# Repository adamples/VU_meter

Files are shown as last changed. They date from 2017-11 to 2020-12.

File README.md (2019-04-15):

# OLED display VU meter — AVR/Arduino project

This project is to create digital version of a nice gadget that adds a little magic 
to any audio equipment: a [VU meter](https://en.wikipedia.org/wiki/VU_meter). Main design
goals are:
  - 2-channel operation,
  - as close to real VU-meter specification as possible,
  - high FPS, 60+ — no visible jumping of needle, as is common in other designs.

Project uses AVR ATMega88/168/328 (and ATMega48 if possible), so should be compatibile with
Arduino Uno boards. Small (and cheap) monochrome OLED modules with SSD1306 or SH1106 driver are 
employed as displays. Unlike other AVR VU meters that you can find on the web this one uses
quite complex analog circuitry (it can be much simpler if you are not as interested as me in
up-to-specs VU meter emulation).

Here's a video showing test of VU meter prototype:

Background and needle animation test video (https://www.youtube.com/watch?v=tU8fmWirxTw)

## Building The Project

To build hex file you'll need:
  - avr-gcc,
  - GNU make,
  - Python 2.7 or 3.
For windows you can use this distribution of gcc and make: http://blog.zakkemble.co.uk/avr-gcc-builds/

Before compilation please modify [src/config.h](src/config.h) file to set proper OLED controller type and [Makefile](Makefile) to set uC type and oscillator frequency (F_CPU).

To create hex file type:
```
$ make all
```
This will create `build/main.hex` that you can use to flash your device.

__Note: This is Work In Progress design. To make it work for you you'll most probably need to modify it in one way or another.__

## Hardware Design

If you would like to make VU meter yourself here are some useful files for you:
  - [hardware/vu_meter.sch](hardware/vu_meter.sch) — schematic (in Eagle 8 format)
  - [hardware/vu_meter.brd](hardware/vu_meter.brd) — PCB design (in Eagle 8 format)
  - [hardware/vu_meter_sch.pdf](hardware/vu_meter_sch.pdf) — schematic as PDF
  - [hardware/bom.ods](hardware/bom.ods) — bill of materials (open document)
  - [hardware/vu_meter.zip](hardware/vu_meter.zip) — gerber files ready for production

PCB is designed as a module to be included in other devices so all signals are connected using goldpin headers:
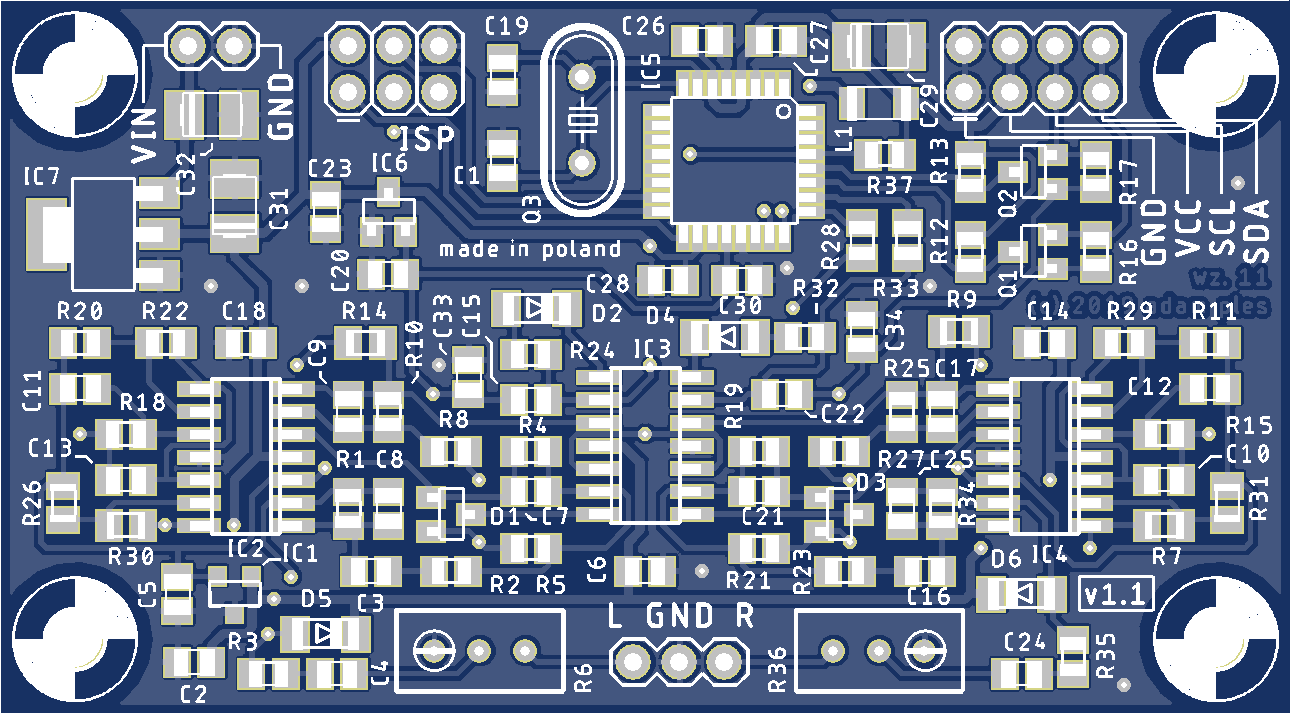
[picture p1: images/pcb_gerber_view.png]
VU meter PCB design preview

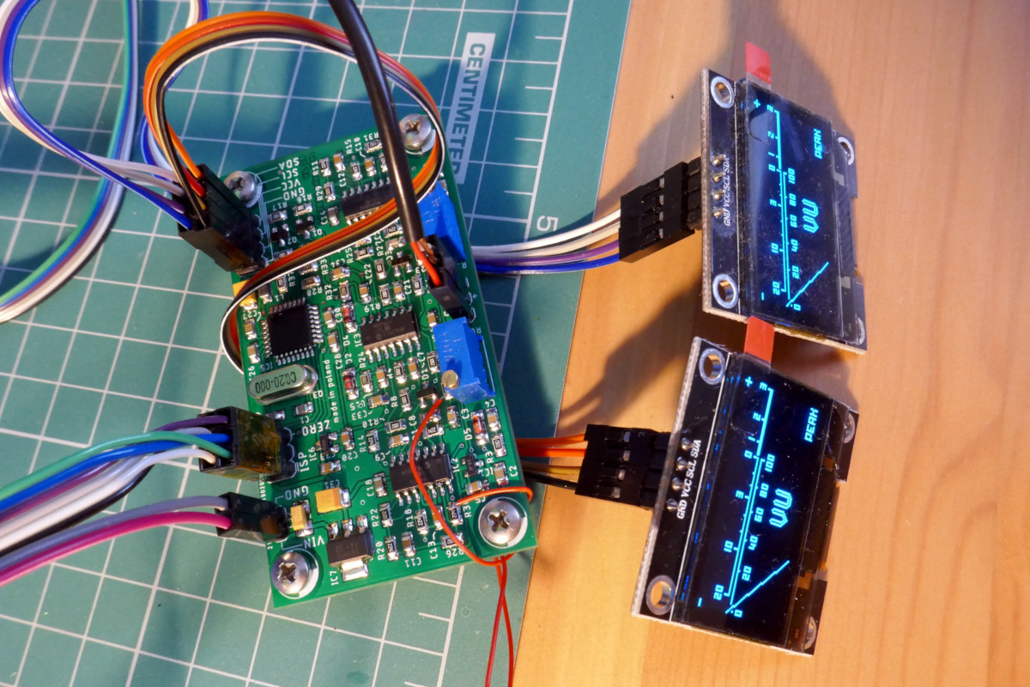
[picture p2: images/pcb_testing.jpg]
Assembled VU meter PCB picture


There is also Arduino UNO shield (rev.3) design, altough it's not very polished version:
  - [hardware/arduino_shield.sch](hardware/arduino_shield.sch) — schematic (in Eagle 8 format)
  - [hardware/arduino_shield.brd](hardware/arduino_shield.brd) — PCB design (in Eagle 8 format)

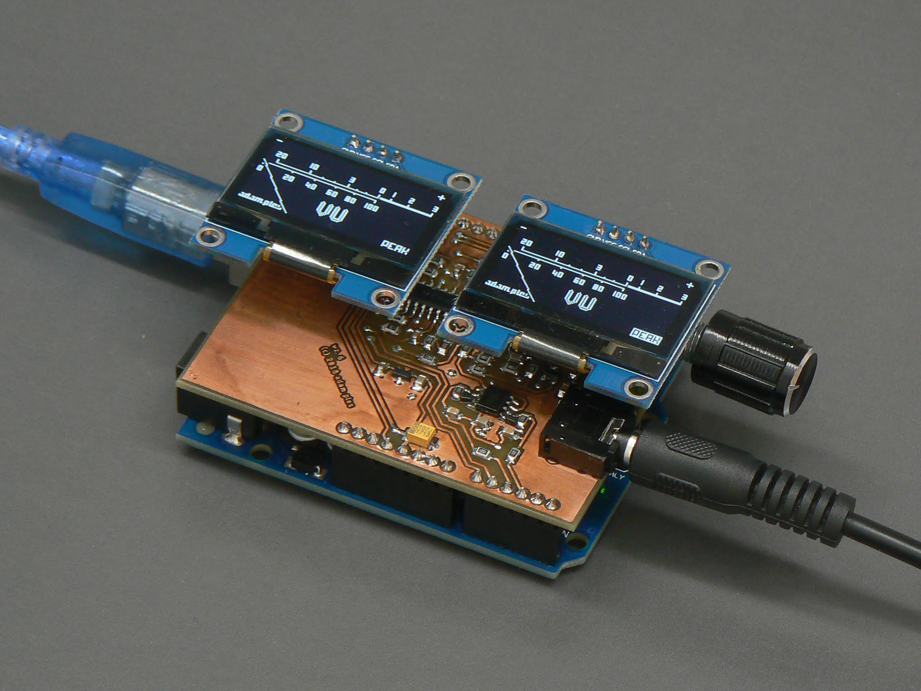
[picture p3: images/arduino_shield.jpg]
Assembled Arduino Shield PCB picture


Full documentation will be included in the future, as the project progresses.

For now here's very high-level block diagram of the device:

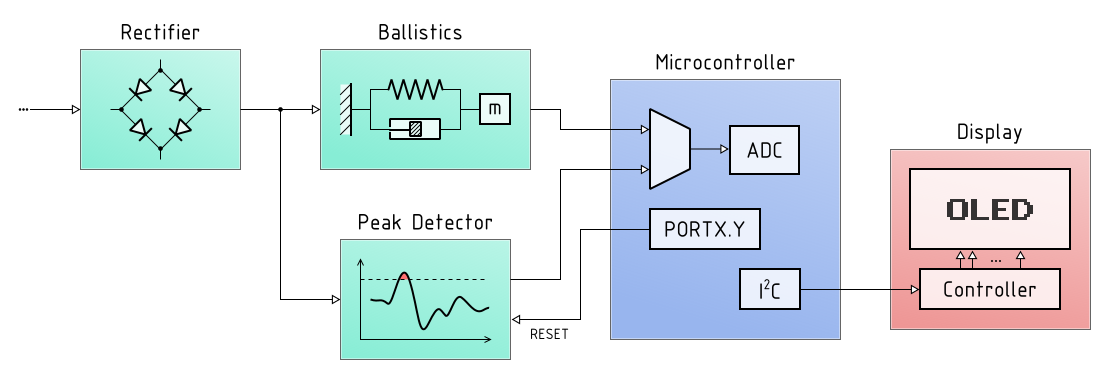
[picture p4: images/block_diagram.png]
Block diagram of AVR/OLED VU meter


Second analog channel and OLED display were omitted for the sake of brevity.

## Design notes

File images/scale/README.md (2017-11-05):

# Defining VU meter scale

To convert from _VU_ scale to _dBu_ we just add 4, so 0VU becomes +4dBu. _dBu_ scale can converted to V<sub>RMS</sub> using equation:
U_Vrms = sqrt(0.6) * 10^(U_dBu/20)

If we assume that VU meter scale will range from 0V<sub>rms</sub> to 1.734V<sub>rms</sub> (+3VU) and the needle can from vertical position by +-42° we get following angles for VU values:

| U [VU] | U [dBu] | U [V<sub>rms</sub>] | angle [°] |
|--:|--:|--:|--:|
|-20|-16|0.123V|-35°|
|-19|-15|0.138|-34|
|-18|-14|0.155|-33|
|-17|-13|0.173|-32|
|-16|-12|0.195|-32|
|-15|-11|0.218|-30|
|-14|-10|0.245|-29|
|-13| -9|0.275|-28|
|-12| -8|0.308|-26|
|-11| -7|0.346|-24|
|-10| -6|0.388|-22|
| -9| -5|0.436|-20|
| -8| -4|0.489|-18|
| -7| -3|0.548|-15|
| -6| -2|0.615|-12|
| -5| -1|0.690| -8|
| -4| +0|0.775| -4|
| -3| +1|0.869|  0|
| -2| +2|0.975|  5|
| -1| +3|1.094| 11|
| +0| +4|1.228| 17|
| +1| +5|1.377| 24|
| +2| +6|1.546| 32|
| +3| +7|1.734| 41|

For percentage scale we get the following:

| U [% 0dBu] | U [V<sub>rms</sub>] | angle [°] |
|--:|--:|--:|
|0|0.000|-41|
|5|0.061|-38|
|10|0.123|-35|
|15|0.184|-32|
|20|0.246|-29|
|25|0.307|-26|
|30|0.368|-23|
|35|0.430|-20|
|40|0.491|-18|
|45|0.552|-15|
|50|0.614|-12|
|55|0.675| -9|
|60|0.737| -6|
|65|0.798| -3|
|70|0.859|  0|
|75|0.921|  3|
|80|0.982|  5|
|85|1.044|  8|
|90|1.105| 11|
|95|1.166| 14|
|100|1.228| 17|

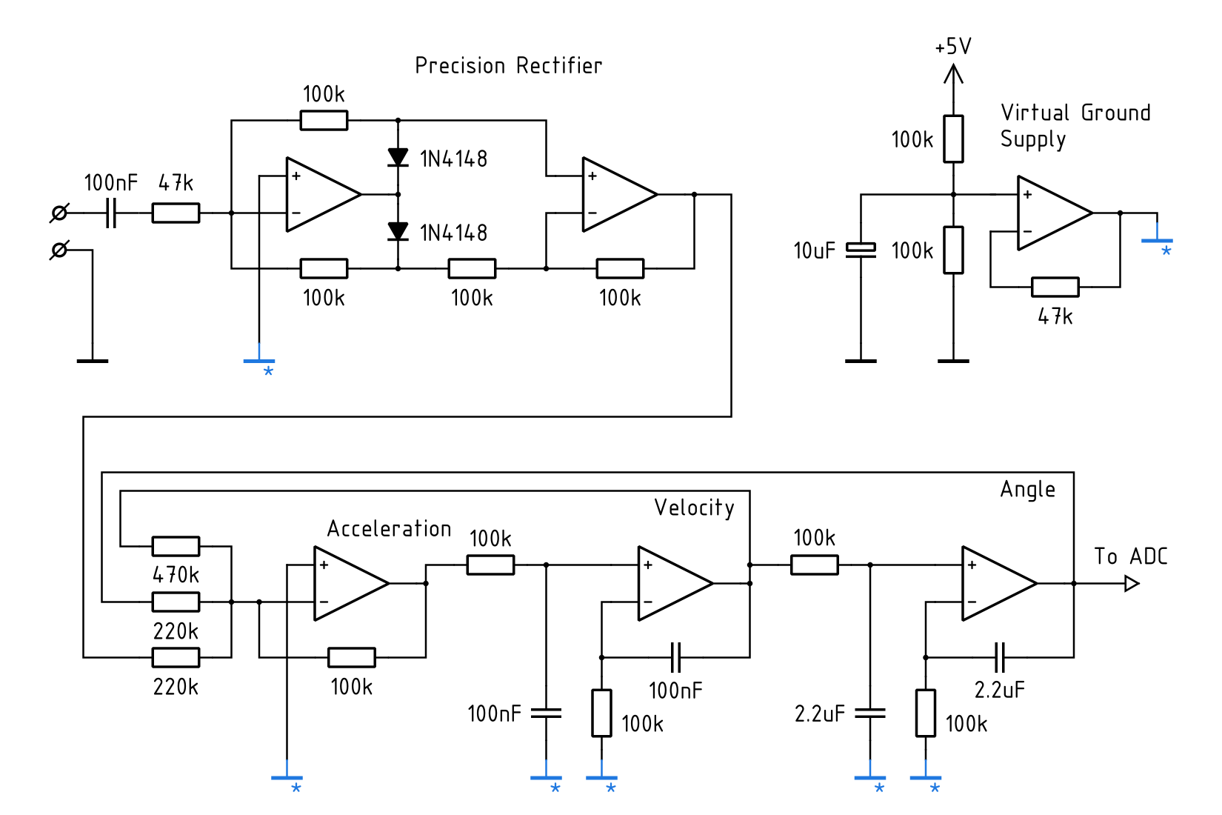
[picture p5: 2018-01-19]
images/analog_simulation.png

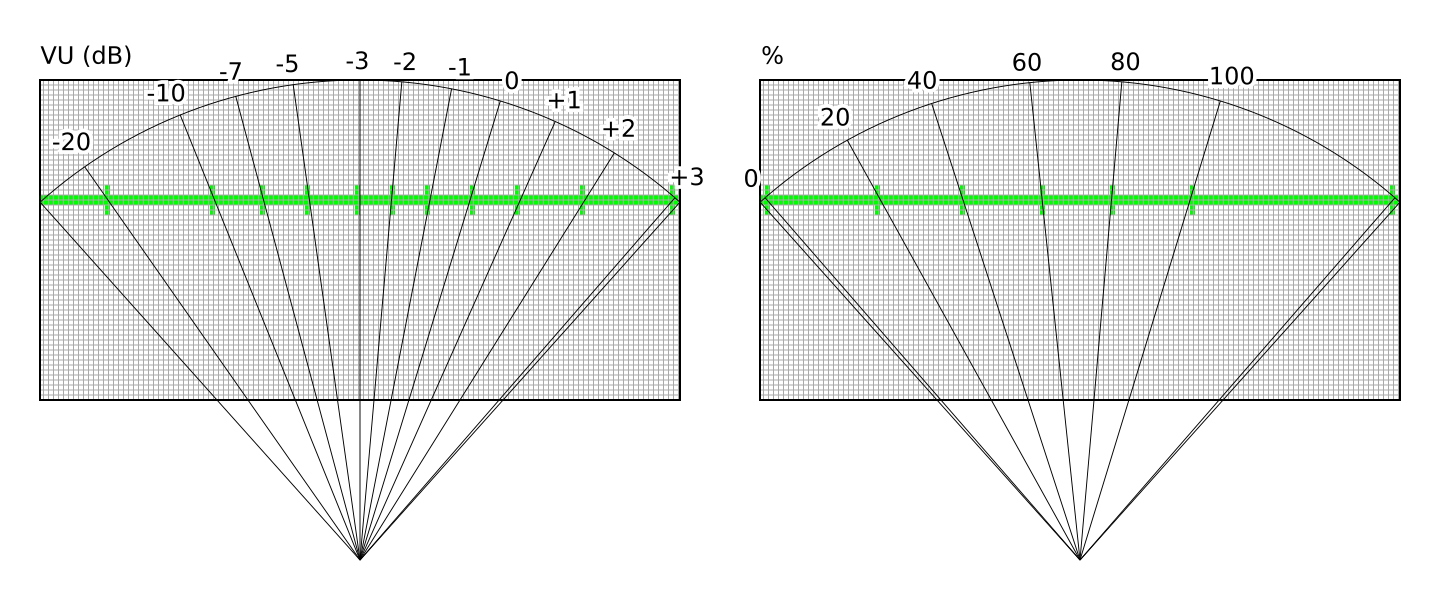
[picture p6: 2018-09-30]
images/scale/scale.png

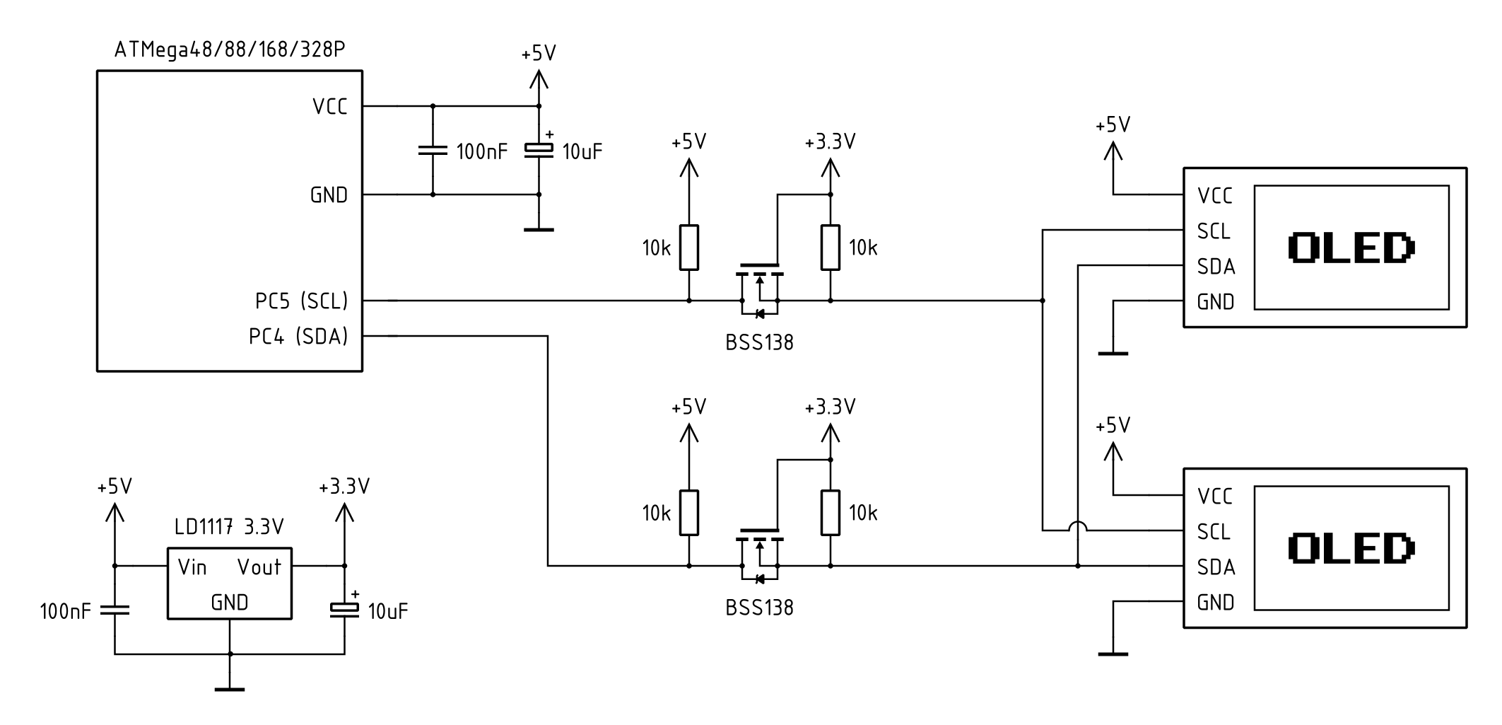
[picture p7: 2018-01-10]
images/oled_connection.png

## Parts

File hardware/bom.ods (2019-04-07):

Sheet: Short
Part Name | Technology | Package | Value | Add. Params | Quantity
Resistors | thin film | 0805 | 10k | 1% | 15
 | thick film | 0805 | 220R |  | 2
 |  |  | 1k |  | 2
 |  |  | 22k |  | 2
 |  |  | 47k |  | 2
 |  |  | 82k |  | 2
 |  |  | 220k |  | 10
 | trimmer | 3296W | 10k |  | 2
Capacitors | ceramic | 0805 | 22pF |  | 2
 |  |  | 33pF |  | 2
 |  |  | 220pF |  | 4
 |  |  | 47nF |  | 2
 |  |  | 100nF |  | 10
 |  |  | 220nF |  | 2
 |  |  | 330nF |  | 4
 |  |  | 470nF |  | 2
 |  |  | 1uF |  | 2
 |  |  | 10uF |  | 1
 | tantalum | 1210 | 10uF | 16V | 1
 |  |  | 100uF | 6.3V | 2
Diodes |  | SOD80 | 1N4148 |  | 2
 |  |  | BAT85 |  | 2
 |  | SOT23 | BAS70-04 |  | 2
Transistors |  | SOT23 | BSS138 |  | 2
Integrated Circuits | linear regulator | SOT223 | 1117-5.0 |  | 1
 |  | SOT23 | MCP1700*33 |  | 1
 |  | SOT23 | MCP1525 |  | 1
 | op amp | SO14 | MCP604 |  | 1
 |  |  | MCP6004 |  | 2
 | microcontroller | TQFP32 | ATmega88P |  | 1
Others | crystal resonator | HC49/S | 20MHz |  | 1
 | choke | 1210 | 10uH |  | 1
 | pin headers |  | 1x2 |  | 1
 |  |  | 1x3 |  | 1
 |  |  | 2x3 |  | 1
 |  |  | 2x4 |  | 1

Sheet: Full
Part Name | Technology | Package | Value | Part Name | Add. Params
Resistors | thin film | 0805 | 10k | R2 | 1%
 |  |  |  | R4 | 1%
 |  |  |  | R5 | 1%
 |  |  |  | R8 | 1%
 |  |  |  | R10 | 1%
 |  |  |  | R19 | 1%
 |  |  |  | R21 | 1%
 |  |  |  | R23 | 1%
 |  |  |  | R25 | 1%
 |  |  |  | R27 | 1%
 | thick film | 0805 | 220R | R24
 |  |  |  | R32
 |  |  | 1k | R28
 |  |  |  | R33
 |  |  | 10k | R12
 |  |  |  | R13
 |  |  |  | R16
 |  |  |  | R17
 |  |  |  | R37
 |  |  | 22k | R3
 |  |  |  | R35
 |  |  | 47k | R26
 |  |  |  | R31
 |  |  | 82k | R22
 |  |  |  | R29
 |  |  | 220k | R1
 |  |  |  | R7
 |  |  |  | R9
 |  |  |  | R11
 |  |  |  | R14
 |  |  |  | R15
 |  |  |  | R18
 |  |  |  | R20
 |  |  |  | R30
 |  |  |  | R34
 | trimmer | 3296W | 10k | R6
 |  |  |  | R36
Capacitors | ceramic | 0805 | 22pF | C1
 |  |  |  | C19
 |  |  | 33pF | C8
 |  |  |  | C25
 |  |  | 220pF | C7
 |  |  |  | C9
 |  |  |  | C17
 |  |  |  | C21
 |  |  | 47nF | C15
 |  |  |  | C22
 |  |  | 100nF | C2
 |  |  |  | C6
 |  |  |  | C14
 |  |  |  | C18
 |  |  |  | C26
 |  |  |  | C27
 |  |  |  | C28
 |  |  |  | C30
 |  |  |  | C33
 |  |  |  | C34
 |  |  | 220nF | C4
 |  |  |  | C24
 |  |  | 330nF | C10
 |  |  |  | C11
 |  |  |  | C12
 |  |  |  | C13
 |  |  | 470nF | C3
 |  |  |  | C16
 |  |  | 1uF | C5
 |  |  |  | C23
 |  | 0805 | 10uF | C20
 | tantalum | 1210 | 10uF | C32 | 16V
 |  |  | 100uF | C29 | 6.3V
 |  |  |  | C31 | 6.3V
Diodes |  | SOD80 | 1N4148 | D2
 |  |  |  | D4
 |  |  | BAT85 | D5
 |  |  |  | D6
 |  | SOT23 | BAS70-04 | D1
 |  |  |  | D3
Transistors |  |  | BSS138 | Q1
 |  |  |  | Q2
Integrated Circuits | linear regulator | SOT223 | 1117-5.0 | IC7
 |  | SOT23 | MCP1700*33 | IC6
 |  | SOT23 | MCP1525 | IC1
 | op amp | SO14 | MCP604 | IC3
 |  |  | MCP6004 | IC2
 |  |  |  | IC4
 | microcontroller | TQFP32 | ATmega88P | IC5
Others | crystal resonator | HC49/S | 20MHz | Q3
 | choke | 1210 | 10uH | L1

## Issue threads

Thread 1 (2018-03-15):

Screen refresh rate

capezoloh, 2018-03-15:
Neat little project you got here. Most of these kind of projects I see on youtube have really poor screen update rate. Is this true for yours aswell?

adamples, 2018-03-16:
Yeah, I also noticed it. There are several reasons for this. Most projects use u8g2, which is a great general-purpose library, but with some limitations arising from it's design goals. In the picture loop mode it refreshes the whole screen, which takes considerable amount of time just to transfer the data (~24ms for I2C at 400kHz). Additionally it uses synchronous I2C driver, so it can't render while sending the data either. This yields FPS in range of 20+.

In this project I aimed at different approach: asynchronous I2C, using HW available in atmega, and partial screen updates. It also uses sprites instead of drawing primitives directly to buffer. It all requires additional data and flash memory, but in the end you get update time of ~7ms, so more than 60FPS for 2 displays (it's more than display's actual frame rate I believe). It gives an impression of really smooth movement.

The code was tailored for purpose of displaying the needle against fixed background. It can be changed to do picture-loop style drawing or to use framebuffer, and calculating an update can be generalized too, but it's not the purpose of this project.

RaffRJ, 2018-05-05:
Hi Adam.
Its me raffy turc on youtube.
I have downloaded and installed python 3.6 and compiled the 2 py files. Im getting error. What could be possibly the problem?

adamples, 2018-05-05:
@RaffRJ Can you please open new issue for this? Also, you have to provide at least some error message, describe what commands you executed. Otherwise it's really hard to tell.

Closed 2018-05-05.

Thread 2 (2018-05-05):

Compiling problems in windows

RaffRJ, 2018-05-05:
Using windows 64-bit machine

What I have done:
Copy the make.exe inside a folder with the SRC folder in it. When I envoke make, 1st problem  it was looking for missing file.
[IMG]http://i65.tinypic.com/3145mhh.jpg[/IMG]

Now I have downloaded and installed python 3.6

Run the app and loaded python files. It returns error.
[IMG]http://i63.tinypic.com/34t1gup.jpg[/IMG]

adamples, 2018-05-06:
Ok, now I see the problem.

First of all you shouldn't copy `make` into repository. You just need to add it's directory to the PATH environment variable. Then you'll be able to run it from any directory. _Please remove it before proceeding with these instructions_.

Let's say you downloaded avr-gcc from here: http://blog.zakkemble.co.uk/avr-gcc-builds/ and unpacked to `C:\avr-gcc-7.3.0-x64-mingw\`. Then you open cmd, and add it to your PATH:

```
C:\vum> set PATH=C:\avr-gcc-7.3.0-x64-mingw\bin\;%PATH%
```

_Please double check if this is a valid path to bin directory, which contains `avr-gcc.exe` and `make.exe`_.

Now you can check if avr-gcc is recognized as a command:

```
C:\vum> avr-gcc --version
avr-gcc (GCC) 7.3.0
Copyright (C) 2017 Free Software Foundation, Inc.
This is free software; see the source for copying conditions.  There is NO
warranty; not even for MERCHANTABILITY or FITNESS FOR A PARTICULAR PURPOSE.
```

Same with make:

```
C:\vum> make --version
GNU Make 4.2.1
Built for Windows32
Copyright (C) 1988-2016 Free Software Foundation, Inc.
License GPLv3+: GNU GPL version 3 or later <http://gnu.org/licenses/gpl.html>
This is free software: you are free to change and redistribute it.
There is NO WARRANTY, to the extent permitted by law.
```

And Python:

```
C:\vum> python --version
Python 3.6.5
```

If all of that works, just execute `make` and you should get your `build\main.hex` file.

If you want to add avr-gcc to PATH permamently, use `setx` command:

```
C:\vum> setx PATH=C:\avr-gcc-7.3.0-x64-mingw\bin\;%PATH%
```

RaffRJ, 2018-05-07:
Update:

Hardware now working. Xtal changed to 20MHz. I have tried your older code and meter needle never moves. Tried all analog inputs.

And then I compiled again your latest code "using single lcd" . Now the meter shows pegged. Still no response from analog input pin/s (assuming this gets audio signal from A0)
[IMG]http://i68.tinypic.com/se7qq1.jpg[/IMG]

RaffRJ, 2018-05-07:
Got it!

So this is using Aref.no wonder 😀. My bad. Anyways at what voltage does the final op-amp output is with 0v input signal? Around 2.5v? Assuming using rail2rail output? I have here mcp602. Havent wired it yet according to your diagram.

adamples, 2018-05-07:
Yes, it will be somewhere around virtual ground, so 2.5V. If I remember correctly with input of sine wave with amplitude of ~0.5V it goes down to around 1.3V (I may be wrong about that, I tried many versions of this circuit).

In this code (main.c:93):
```
int16_t angle_l = (int32_t) (498 - adc_l) * 128 / 164;
```

498 is "zero" level, and 164 is scaling factor. You can adjust it to be more or less sensitive. Additionally you can change gain of input stage by changing the 47k resistor.

In my prototype I used mcp6002 which has both rail-to-rail inputs and outputs.

RaffRJ, 2018-05-07:
Copy that. So if I change 498 to 0, would this mean also as "referenced to GND"?

and how do I turn off or disable Aref?

RaffRJ, 2018-05-09:
Adam

I have tried value of 800. The needle is in the "peg" position. And when I touch op-amp input, meter deflects to left. Quiet the opposite from your video. What couls be problem here? Its like the adc is configured for "reverse"

RaffRJ, 2018-05-09:
Adam.

Dis-regard my earlier post. Its working ok now. Ive scoped out the output of op-amp circuit. It registers virtual ground+sensed audio(positive voltage). It was the code that was inverting the results. Done some bit of google search(my mind kinda rusty with coding 😂) . Will rotate again 180° the bitmap image to "standard" orientation. Though I may add a bit of hardware mod at the adc input. Adjustable midpoint voltage then ac couple it to the op-amp/s front-end so I wouldnt be bothered adjusting code for "zero-ing""the meter needle.

Better if I could assign an un-used adc input to pot and map it (adding integer value) to the AN0 reading..but thats out of my head now.
Will update a video later...

Could you suggest me an easier way of "zero-ing"  the needle on your code?
Was thinking 8-bits(?) so 1024(or 1023) divide that in half since op-amp is referenced to 1/2 vcc.
Then add maybe in increments of 5 ..you get my point.. lol.

I need some sleep 1st. Laters man!  And thanks for this vu project of yours.
Nice addition to my desktop eycandy oled display/s.

adamples, 2018-05-14:
Ok, I added quick fix to both main and single_display branches: https://github.com/adamples/VU_meter/commit/e31dd53ddfc5ed11ee5e7e64ef18e89d4039c249

Currently the code checks for needle angle to make peak indicator visible (main.c:106):

```
PEAK_INDICATOR_SPRITE.sprite.visible = (angle_l > 192);
```

Closed 2018-05-23.

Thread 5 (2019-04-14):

The Circuit Diagram

classic-audio, 2019-04-14:
I am back and I am still thinking of building this great project.
To start - I would like to start with the circuit diagram /PCB.
I tried to open your eagle files in eagle 9.2.2  - but I am getting the message: This is not an eagle file.
I can open eagle files from eagle 6.x in eagle 9.2.2 so I expect also that eagle 8.x files should be possible to open but no.
Do you know a reason ?
Or would you be so kind to send the circuit in a PDF file?
Best regards
Frede Kristensen

adamples, 2019-04-15:
Did you try these files? (I put the wrong names in readme by mistake)
https://github.com/adamples/VU_meter/blob/master/hardware/vu_meter_2.sch
https://github.com/adamples/VU_meter/blob/master/hardware/vu_meter_2.brd

I will fix that and add schematic in pdf later today.

adamples, 2019-04-15:
I uploaded the circuit diagram here:
https://github.com/adamples/VU_meter/blob/master/hardware/vu_meter_sch.pdf

classic-audio, 2019-04-15:
Thank you very much. Really interresting for me to study you solution.
(The analog circuit).
I will have a look to night.

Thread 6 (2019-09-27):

Programming

shtv-electro, 2019-09-27:
Hello. Tell me how to program a project (I am using Atmega328P (Arduino nano), 16MHz, OLED1306). I am not familiar with Python language, and would like more detailed instruction. Thanks

adamples, 2019-10-09:
Hi, if you know how to flash your arduino with hex file you can use the ones from this zip: https://github.com/adamples/VU_meter/releases. It doesn't require Python.

shtv-electro, 2019-10-22:
Hey. I flashed a hexadecimal file, the screen is black. Tried to flash the standard code of the display and it works. Maybe your code is not the address of the display? I want you ask do code under displays 1306 with addresses: 0x3C; 0x3C. Atmega328p, 16 MHz.

adamples, 2019-10-25:
Hi, it won't work since display addresses need to be different. If you're able to change address of one of them (probably by resoldering some resistor on board) then I can compile hex file for you.

Juroo5, 2020-10-15:
Hello, I'm joining DamianRaistrick's previous question. I'm trying to run a program on an Arduino Nano (Atmega328P). I have displays with the SD1309 controller (exactly these https://www.aliexpress.com/item/33024448944.html?spm=a2g0s.9042311.0.0.27c64c4dNouTa4)
The displays are connected in I2C mode to arduino (PC5 -> SCL, PC4 -> SDA) . On one, the address is changed by changing the CS level. With the I2C scanner the addresses are 0x3C and 0x3D.
In the makefile I changed :
BOARD? = WZ10 to BOARD? = ARDUINO_UNO
In config file I changed :
#define OLED_DRIVER (OLED_DRIVER_SD1309)
...
#define DISPLAY_A_ADDRESS (0x3C)
#define DISPLAY_B_ADDRESS (0x3D)
...
After uploading the program (with generated HEX and AVRDUDESS), nothing will appear on the displays.
It's possible that arduino I2C scanner (scanner in arduino example sketchs) see different address than this program ?
Or is there something I missed ? Can you help me? Thank you.

adamples, 2020-10-15:
Hi! One common problem is that those displays even when using the same driver designation are not always exactly the same. I think this one may need reset signal during initialization. Have you tried displaying something using other libraries/arduino sketches? If so, which library and how did you connect the reset line?

Juroo5, 2020-10-15:
Hi! Thank you for the quick reply. For the reset pin I connected a 22uf capacitor between RES and GND and a 10k resistor between VCC and RES. Yes, I tested these displays on the example of Adafruit SSD1306 library : https://photos.app.goo.gl/9cgTZD8fZcefB1yZA
It's of course OLED_DRIVER_SSD1309, I'm sorry for the bad typing.
In the end, it works! Well thank you ! The problem was the addresses, I correct them to 0x78 and 0x7a and it works.

cghercoias, 2020-12-20:
Hi Adam,

I just found your project and I must say it is impressive. I have just one SH1106 display and I wanted to try your code. I did compile successfully the code on my Mac, changing in the makefile. But the display does not lit.
It is wired just GND, VCC, SDA and SCL. I did test the display with the Adafruit example code for this display and works fine. When I upload the main.hex does not lit anymore.  The address on the back of the display (where the resistor is soldered) is 0x78. However, in the Adafruit example is 0x3C and works. In the config.h is 0x78 and 0x7A. I did try and compile the main.hex with 0x3C for DISPLAY_A_ADDRESS and 0x3D for DISPLAY_B_ADDRESS and still didn't show anything on the display.
I don't know where to look anymore.
..
BOARD? = WZ10 to BOARD? = ARDUINO_UNO
..
Here is how I am burning the main.hex file on the ArduinoNANO

catalin@DadMacPro VU_meter-master % /Users/catalin/Library/Arduino15/packages/arduino/tools/avrdude/6.3.0-arduino17/bin/avrdude -C/Users/catalin/Library/Arduino15/packages/arduino/tools/avrdude/6.3.0-arduino17/etc/avrdude.conf -v -patmega328p -carduino -P/dev/cu.usbserial-1410 -b115200 -D -Uflash:w:build/RELEASE/main.hex:i

avrdude: Version 6.3-20190619
         Copyright (c) 2000-2005 Brian Dean, http://www.bdmicro.com/
         Copyright (c) 2007-2014 Joerg Wunsch

         System wide configuration file is "/Users/catalin/Library/Arduino15/packages/arduino/tools/avrdude/6.3.0-arduino17/etc/avrdude.conf"
         User configuration file is "/Users/catalin/.avrduderc"
         User configuration file does not exist or is not a regular file, skipping

         Using Port                    : /dev/cu.usbserial-1410
         Using Programmer              : arduino
         Overriding Baud Rate          : 115200
         AVR Part                      : ATmega328P
         Chip Erase delay              : 9000 us
         PAGEL                         : PD7
         BS2                           : PC2
         RESET disposition             : dedicated
         RETRY pulse                   : SCK
         serial program mode           : yes
         parallel program mode         : yes
         Timeout                       : 200
         StabDelay                     : 100
         CmdexeDelay                   : 25
         SyncLoops                     : 32
         ByteDelay                     : 0
         PollIndex                     : 3
         PollValue                     : 0x53
         Memory Detail                 :

                                  Block Poll               Page                       Polled
           Memory Type Mode Delay Size  Indx Paged  Size   Size #Pages MinW  MaxW   ReadBack
           ----------- ---- ----- ----- ---- ------ ------ ---- ------ ----- ----- ---------
           eeprom        65    20     4    0 no       1024    4      0  3600  3600 0xff 0xff
           flash         65     6   128    0 yes     32768  128    256  4500  4500 0xff 0xff
           lfuse          0     0     0    0 no          1    0      0  4500  4500 0x00 0x00
           hfuse          0     0     0    0 no          1    0      0  4500  4500 0x00 0x00
           efuse          0     0     0    0 no          1    0      0  4500  4500 0x00 0x00
           lock           0     0     0    0 no          1    0      0  4500  4500 0x00 0x00
           calibration    0     0     0    0 no          1    0      0     0     0 0x00 0x00
           signature      0     0     0    0 no          3    0      0     0     0 0x00 0x00

         Programmer Type : Arduino
         Description     : Arduino
         Hardware Version: 3
         Firmware Version: 4.4
         Vtarget         : 0.3 V
         Varef           : 0.3 V
         Oscillator      : 28.800 kHz
         SCK period      : 3.3 us

avrdude: AVR device initialized and ready to accept instructions

Reading | ################################################## | 100% 0.00s

avrdude: Device signature = 0x1e950f (probably m328p)
avrdude: safemode: lfuse reads as 0
avrdude: safemode: hfuse reads as 0
avrdude: safemode: efuse reads as 0
avrdude: reading input file "build/RELEASE/main.hex"
avrdude: writing flash (5762 bytes):

Writing | ################################################## | 100% 1.03s

avrdude: 5762 bytes of flash written
avrdude: verifying flash memory against build/RELEASE/main.hex:
avrdude: load data flash data from input file build/RELEASE/main.hex:
avrdude: input file build/RELEASE/main.hex contains 5762 bytes
avrdude: reading on-chip flash data:

Reading | ################################################## | 100% 0.77s

avrdude: verifying ...
avrdude: 5762 bytes of flash verified

avrdude: safemode: lfuse reads as 0
avrdude: safemode: hfuse reads as 0
avrdude: safemode: efuse reads as 0
avrdude: safemode: Fuses OK (E:00, H:00, L:00)

avrdude done.  Thank you.
...

adamples, 2020-12-21:
So the addresses in config should be 0x78/0x7a. 0x3c and 0x3d is the same address written in different convention (it's just right-shifted by 1 bit). Did you try to connect two displays or just one? It's not clear from your question. This project requires two with different addresses, otherwise it won't display anything.

cghercoias, 2020-12-21:
0x3C | 0 0 1 1   1 1 0 0
0x3D | 0 0 1 1   1 1 0 1

0x78 | 0 1 1 1   1 0 0 0
0x7A | 0 1 1 1   1 0 1 0

I see that now, it is right-shifted. How come I didnt see that before. :-)
I connected only one display, SH1106. I will try with two SSD1306 as I dont have two SH1106s.
Thank you so much

cghercoias, 2020-12-22:
I made it work with 2 SSD1306s. Had to modify the address of one of them by cutting a pad and solder it to VCC.
Pictures attached.
According to SSD1306 PDF document ( [SSD1306.pdf](https://github.com/adamples/VU_meter/files/5732094/SSD1306.pdf) - page 20 ) :

_"The slave address is following the start condition for recognition use. For the SSD1306, the slave
address is either “b0111100” or “b0111101” by changing the SA0 to LOW or HIGH (D/C pin acts as
SA0)."_
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

So, I did a little surgery on one display, D/C pin aka SA0 is pin 15:
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

Final result:
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

THANK YOU SO MUCH ADAM !!!

Merry Christmas and a Happy New Year! Stay safe!

adamples, 2020-12-23:
Very glad to hear it worked for you, Marry Christmas to you too!

cghercoias, 2020-12-23:
Now I have another issue. The needles don't move. I've applied a signal from my laptop headphone jack on both A0 and A1 (inserted 1uF electrolytic capacitor on each channel to decouple any DC component, if present) and the only thing that sometimes happens is PEAK blinks. Looking at your electronics diagram, I noticed you've connected ARef to 3.3V. So I placed a jumper between 3.3V and ARef (behind those resistors) and the needles jumped to max and stayed there. I'm able to watch with the osciloscope the audio signal getting to A0 and A1, I can vary the amplitude from 0 to 1.5V. I did not connect anything to the A2 and A3 for PEAK. What am I missing?

adamples, 2020-12-25:
Well, if you're using different analog circuitry at the inpuit it will require some hacking on your part. The program is expecting AREF to be 3.3V and voltage when there is no signal at the input should be 2.5V (there is 2.5V reference source on the schematic, MCP1525 IIRC). When needle is at 0VU the voltage at the input should go _down_ to about 1.1V. You can find the code in calibration.h/c.

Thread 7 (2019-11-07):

Display Question

DamianRaistrick, 2019-11-07:
Hi Adam
Really excellent project!
I'm attempting to get this to work on a couple of SH1106 displays with addresses 0x3c and 0x3d. I've managed to edit the config.h file to reflect the addresses and make the main.hex file (using terminal on my mac). I have managed to upload to an Arduino Uno using HexUploader but nothing appears on the displays.
I've tested the displays using the adafruit and U8Glib example code and they work fine on on I2C.
Is there anything else I should be adjusting before making the hex file for these displays?
Many thanks
Damian

adamples, 2019-11-08:
Hi! Yes, in fact you need to edit BOARD variable in Makefile: replace "BOARD?=WZ10" in 2nd line with "BOARD?=ARDUINO_UNO".

This project may not be of the same quality as u8glib, so if it still doesn't work, let me know ;)

DamianRaistrick, 2019-11-08:
Thanks so much Adam
Your project is inspiring! I only mentioned the other libraries/examples because I wanted to show I'd tested my displays were generally working ok with I2C.
I knew there was something I was doing wrong! :)
I'll try editing the Board variable as you suggest and let you know how I get on.
Thanks again
Damian

DamianRaistrick, 2019-11-08:
Hello again!
I edited the make file as instructed, but sadly I still have a blank display.
I wonder if trying a windows environment (rather than my mac) would make any difference?!
Incidentally the displays I'm using are these:
https://hobbycomponents.com/displays/621-3-sh1106-uoled-display-module-white
with the jumper set for I2C. DC pin sets the address to either 0x3C or 0x3D. CS tied to ground and RES is the reset pin normally tied to High.
Any other ideas?
Thanks
Damian

DamianRaistrick, 2019-11-08:
I've just tried an experiment to check HexUploader was flashing the Uno properly. I exported a hex file from the Arduino IDE of the Adafruit example code and flashed that using HexUploader and it worked fine.
So it looks like there's still something I'm doing wrong with the compiling of the hex file for your code.

DamianRaistrick, 2019-11-11:
Hi again Adam
OK, so now I have bought some different I2C displays (1306) and I've tried the code you have already complied to hex with my Uno (using your mega328p_16Mhz.hex) and things still don't work for me - blank displays again.
Going back to compiling myself - with my new 1306 I2C displays on 07xA and 07xB - what exactly should I be doing with the config.h file in terms of editing it and running it on my Arduino Uno?
In your readme you say to edit the config.h file to "set proper OLED controller type". My guess is I'm not doing that properly.
I see the list of controller type definitions in the config.h file, but the remark says not to edit these constants. So how should I edit the config.h file to set the controller type to 1306?
Many thanks
Damian

DamianRaistrick, 2019-11-11:
Don't worry! I now realise that these new displays do not have the addresses 0x7A and 0x78 when used with Arduino - they are 0x3C and 0x3D because of the way Arduino truncates the addresses.
The more I use Arduino, the more limited I realise it is!
I've returned the new displays and will now give up! I've wasted so much time trying to get this to work for me.
Nice project though! :-)
Feel free to close this 'issue'.
Best
Damian

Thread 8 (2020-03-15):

PCB Production

ezhik1, 2020-03-15:
Hej @adamples ! Absolute stellar project! I too, find the ballistics and smoothing in analog vu meter very important :) My VU meters, one of my first [here](https://www.youtube.com/watch?v=RjcTkzzANwM), have all been based on lm3916 ICs and with a much larger footprint, so it would be real fun to play with this compact scale!

I saw most of your prototypes on youtube and looks like you've got the board produced already, did you have it made locally, or do you have something already set up with a factory in China?

The BOM you have listed doesn't have designators, but I used Eagle to generate one from the .sch file, and it looks to be complete.

If I get the board produced, I want to make sure I've got the BOM right, Could you have a look?  Also, what was overall parts cost? I'm trying to see how economical this little visualizer will turn out.

Dziekuje!

male pin   header: 1*2pin 2.54mm | 1 |   | CONN_02 | 1X02 | J2 | Multi connection point. Often   used as Generic Header-pin footprint for 0.1 inch spaced/style header   connections |   |   |   |   |   |   |  
-- | -- | -- | -- | -- | -- | -- | -- | -- | -- | -- | -- | -- | --
male pin header: 2*3pin 2.54mm | 1 |   | CONN_03X22X3_SILK_MALE_PTH | 2X3 | J3 | Multi connection point. Often used as Generic Header-pin   footprint for 0.1 inch spaced/style header connections |   |   |   |   | CONN-09701 |   |  
male pin header: 2*4pin 2.54mm | 1 |   | CONN_04X2 | 2X4 | J4 | Multi connection point. Often used as Generic Header-pin   footprint for 0.1 inch spaced/style header connections |   |   |   |   |   |   |  
HC49SM-3.6864-30-50-60-16-ATF   ok? | 1 |   | CRYSTALHC49S | HC49/S | Q3 | CRYSTAL |   |   | 1667008 | unknown |   |   |  
100NF 50V 0805 | 10 | 100nF | C-EUC0805 | C0805 | C2, C6, C14, C18, C26, C27, C28, C30, C33, C34 | CAPACITOR, European symbol |   |   |   |   |   |   |  
Is TANT 100UF 6.3V B3528 part,   ok? | 2 | 100uF | CPOL-EUB/3528-21R | B/3528-21R | C29, C31 | POLARIZED CAPACITOR, European symbol |   |   |   |   |   |   |  
10k 1% 0805 | 15 | 10k | R-EU_R0805 | R0805 | R2, R4, R5, R8, R10, R12, R13, R16, R17, R19, R21, R23, R25,   R27, R37 | RESISTOR, European symbol |   |   |   |   |   |   |  
3296W-1-103LF | 2 | 10k | R-TRIMM3296W | RTRIM3296W | R6, R36 | Trimm resistor |   |   |   |   |   |   |  
10UF 16V 0805 | 1 | 10uF | C-EUC0805 | C0805 | C20 | CAPACITOR, European symbol |   |   |   |   |   | ceramic |  
Is TANT 10UF 16V B3528 ok? | 1 | 10uF | CPOL-EUB/3528-21R | B/3528-21R | C32 | POLARIZED CAPACITOR, European symbol |   |   |   |   |   |   |  
Plz confirm correct part is   CBC3225T100KR | 1 | 10uH | L-EUL3216C | L3216C | L1 | INDUCTOR, European symbol |   |   |   |   |   |   |  
Please confirm correct part is   LL4148 SOD80 | 2 | 1N4148 | DIODE-MINIMELF | MINIMELF | D2, D4 | DIODE |   |   |   |   |   |   |  
1k 1% 0805 | 2 | 1k | R-EU_R0805 | R0805 | R28, R33 | RESISTOR, European symbol |   |   |   |   |   |   |  
1UF 16V 0805 | 2 | 1uF | C-EUC0805 | C0805 | C5, C23 | CAPACITOR, European symbol |   |   |   |   |   | ceramic |  
220R | 2 | 220 | R-EU_R0805 | R0805 | R24, R32 | RESISTOR, European symbol |   |   |   |   |   |   |  
220k 1% 0805 | 4 | 220k | R-EU_M0805 | M0805 | R7, R9, R14, R30 | RESISTOR, European symbol |   |   |   |   |   |   |  
220k 1% 0805 | 6 | 220k | R-EU_R0805 | R0805 | R1, R11, R15, R18, R20, R34 | RESISTOR, European symbol |   |   |   |   |   |   |  
220NF 50V 0805 | 2 | 220nF | C-EUC0805 | C0805 | C4, C24 | CAPACITOR, European symbol |   |   |   |   |   |   |  
220PF 50V 0805 | 4 | 220pF | C-EUC0805 | C0805 | C7, C9, C17, C21 | CAPACITOR, European symbol |   |   |   |   |   |   |  
22k 1% 0805 | 2 | 22k | R-EU_R0805 | R0805 | R3, R35 | RESISTOR, European symbol |   |   |   |   |   |   |  
22PF 50V 0805 | 2 | 22pF | C-EUC0805 | C0805 | C1, C19 | CAPACITOR, European symbol |   |   |   |   |   |   |  
330NF 50V 0805 | 2 | 330n | C-EUC0805 | C0805 | C10, C13 | CAPACITOR, European symbol |   |   |   |   |   |   |  
330NF 50V 0805 | 2 | 330nF | C-EUC0805 | C0805 | C11, C12 | CAPACITOR, European symbol |   |   |   |   |   |   |  
33PF 50V 0805 | 2 | 33pF | C-EUC0805 | C0805 | C8, C25 | CAPACITOR, European symbol |   |   |   |   |   |   |  
S3B-PH-SM4-TB(LF)(SN) | 1 | 455-1750-1-ND | CONN_03 | 1X03 | J1 | Multi connection point. Often used as Generic Header-pin   footprint for 0.1 inch spaced/style header connections |   |   |   |   | XXX-00000 |   | 455-1750-1-ND
470NF 50V 0805 | 2 | 470nF | C-EUC0805 | C0805 | C3, C16 | CAPACITOR, European symbol |   |   |   |   |   |   |  
47k 1% 0805 | 2 | 47k | R-EU_M0805 | M0805 | R26, R31 | RESISTOR, European symbol |   |   |   |   |   |   |  
47NF 50V 0805 | 2 | 47nF | C-EUC0805 | C0805 | C15, C22 | CAPACITOR, European symbol |   |   |   |   |   |   |  
82k 1% 0805 | 2 | 82k | R-EU_R0805 | R0805 | R22, R29 | RESISTOR, European symbol |   |   |   |   |   |   |  
  | 2 | BAS70-04 | BAS70-04 | SOT23 | D1, D3 | Silicon Schottky Diodes |   |   |   |   |   |   |  
Please confirm correct part is   BAS85  SOD80 | 2 | BAT85 | DIODE-MINIMELF | MINIMELF | D5, D6 | DIODE |   |   |   |   |   |   |  
  | 2 | BSS138 | BSS123 | SOT23 | Q1, Q2 | N-CHANNEL MOS FET |   |   |   |   |   |   |  
MCP1525T-I/TT ok? | 1 | MCP1525 | MCP9700SMD | SOT23-3 | IC1 |   |   |   |   |   |   |   |  
MCP1700T-3302E/TT ok? | 1 | MCP1700 3V3 | MCP1703CB | SOT23 | IC6 | 250 mA, 16V, Low Quiescent Current LDO Regulator |   |   |   |   |   |   |  
We will supply MCP6004T-I/SL | 2 | MCP6004 | MCP604SL | SO14 | IC2, IC4 | Quad Op Amp 2.7V to 6.0V Single Supply CMOS |   |   |   |   |   |   |  
We will supply MCP6004T-I/SL | 1 | MCP604SL | MCP604SL | SO14 | IC3 | Quad Op Amp 2.7V to 6.0V Single Supply CMOS |   |   |   |   |   |   |  
ATMEGA88PA-AU ok? | 1 | MEGA88 | MEGA48/88/168-AU | TQFP32-08 | IC5 |   |   |   |   |   |   |   |  
  |   |   |   |   |   |   |   |   |   |   |   |   |  
REG1117  REG1117-ND     5-7work days | 1 | REG1117 | REG1117 | SOT223 | IC7 | 800mA and 1A Low Dropout (LDO) Positive Regulator |   | REG1117 | 1097566 | 14P6981 |   |   |  

adamples, 2020-03-17:
Hi! I'm glad you like the project. I can look into this over the weekend, ok? But please consider this is just a hobby project, so maybe start by building it yourself, before putting it into mass production ;)

I ordered the PCBs in China but sourced parts locally and assembled the thing myself. So for me the cost was around $25 per board (including two displays and a lot of shipping costs). I didn't really care about money when designing this, as again, this was done just for fun, and not for profit.

ezhik1, 2020-03-17:
@adamples thanks for the insight! Yep, will definitely only go for hobby interest at this point. Would like to share with some friends/family, gifts and such :)

adamples, 2020-03-23:
HC49SM-3.6864 is 3.6MHz and SMD, and it should be 20MHz THT, like this one: https://eu.mouser.com/ProductDetail/Crystek-Corporation/CY22AS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 .

100uF caps (C29/C31) can be 6.3V, but I would suggest 10V or 16V. Same for C32: 16V is ok, but 25V is better.

CBC3225T100KR should be fine. You can update footprint in PCB to 3225 just to be sure.

LL4148 is fine. D5/D6 is any schottky diode with low reverse current, so BAS85 is ok (even 4148 would work here too).

MCP1525T-I/TT is ok. MCP1700T-3302E/TT is ok. ATMEGA88PA-AU is ok.

ezhik1, 2020-03-26:
Thank you for this!! agreed on the higher voltage capacitors, I've had plenty blow up on 12v circuits even when they're rated for 16v...just too close and cheap caps and poor tolerances go hand in hand :)

Closed 2020-03-26.

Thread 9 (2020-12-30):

compiling issues with Ubuntu

kuzmanzs, 2020-12-30:
Hi,

I want to compile your excellent VU meter project under Linux.
I have installed avr-gcc.
What should I need extra install to compile Arduino codes?

`avr-gcc -mmcu=atmega88p -DF_CPU="20000000UL" -MD -MP -Wall -Werror -std=c99 -ffunction-sections -fdata-sections -funsigned-char -funsigned-bitfields -fpack-struct -fshort-enums -frename-registers -g -Wa,-ahlmsd=build/RELEASE/utils.lst -O2 -DNDEBUG   -c -o build/RELEASE/utils.o src/utils.c
In file included from src/utils.c:1:0:
src/utils.h:4:21: fatal error: avr/wdt.h: No such file or directory
compilation terminated.
`

make  --version
GNU Make 4.1
Built for x86_64-pc-linux-gnu

avr-gcc --version
avr-gcc (GCC) 5.4.0
Copyright (C) 2015 Free Software Foundation, Inc.

adamples, 2020-12-30:
Hi, can you check if you have avr-libc and binutils-avr installed, and if so, what version?

kuzmanzs, 2021-01-03:
Hi,

binutils-avr is already the newest version (2.26.20160125+Atmel3.6.0-1)
for avr-libc i ahve installed http://download.savannah.gnu.org/releases/avr-libc/avr-libc-2.0.0.tar.bz2

thanks your help

kuzmanzs, 2021-01-03:
I have installed via apt avr-libc and it looks working, thanks.

Closed 2021-01-03.

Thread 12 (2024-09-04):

compiling error with win10

dede0393, 2024-09-04:
hi
This your vu meter project is very good👍👍,
honestly I'm not too familiar with using this method, usually I use arduino and bascom-avr (with a beginner level😅). But I want to try it and I have a problem when compiling it with windows10 and using git bash command,

the is error like this:

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

Wii@DESKTOP-3R6O28K MINGW64 ~/Desktop/avr-gcc-214.1.0-x64-windows/bin
$ make
avr-gcc -mmcu=atmega328p -DF_CPU="16000000UL" -MD -MP -Wall -Werror -std=c99 -ffunction-sections -fdata-sections -funsigned-char -funsigned-bitfields -fpack-struct -fshort-enums -frename-registers -g -Wa,-ahlmsd=build/RELEASE/utils.lst -O2 -DNDEBUG   -c -o build/RELEASE/utils.o src/utils.c
avr-gcc -mmcu=atmega328p -DF_CPU="16000000UL" -MD -MP -Wall -Werror -std=c99 -ffunction-sections -fdata-sections -funsigned-char -funsigned-bitfields -fpack-struct -fshort-enums -frename-registers -g -Wa,-ahlmsd=build/RELEASE/fault.lst -O2 -DNDEBUG   -c -o build/RELEASE/fault.o src/fault.c
avr-gcc -mmcu=atmega328p -DF_CPU="16000000UL" -MD -MP -Wall -Werror -std=c99 -ffunction-sections -fdata-sections -funsigned-char -funsigned-bitfields -fpack-struct -fshort-enums -frename-registers -g -Wa,-ahlmsd=build/RELEASE/benchmark.lst -O2 -DNDEBUG   -c -o build/RELEASE/benchmark.o src/benchmark.c
avr-gcc -mmcu=atmega328p -DF_CPU="16000000UL" -MD -MP -Wall -Werror -std=c99 -ffunction-sections -fdata-sections -funsigned-char -funsigned-bitfields -fpack-struct -fshort-enums -frename-registers -g -Wa,-ahlmsd=build/RELEASE/ring_buffer.lst -O2 -DNDEBUG   -c -o build/RELEASE/ring_buffer.o src/ring_buffer.c
avr-gcc -mmcu=atmega328p -DF_CPU="16000000UL" -MD -MP -Wall -Werror -std=c99 -ffunction-sections -fdata-sections -funsigned-char -funsigned-bitfields -fpack-struct -fshort-enums -frename-registers -g -Wa,-ahlmsd=build/RELEASE/i2c_hw.lst -O2 -DNDEBUG   -c -o build/RELEASE/i2c_hw.o src/i2c_hw.c
avr-gcc -mmcu=atmega328p -DF_CPU="16000000UL" -MD -MP -Wall -Werror -std=c99 -ffunction-sections -fdata-sections -funsigned-char -funsigned-bitfields -fpack-struct -fshort-enums -frename-registers -g -Wa,-ahlmsd=build/RELEASE/i2c.lst -O2 -DNDEBUG   -c -o build/RELEASE/i2c.o src/i2c.c
avr-gcc -mmcu=atmega328p -DF_CPU="16000000UL" -MD -MP -Wall -Werror -std=c99 -ffunction-sections -fdata-sections -funsigned-char -funsigned-bitfields -fpack-struct -fshort-enums -frename-registers -g -Wa,-ahlmsd=build/RELEASE/oled.lst -O2 -DNDEBUG   -c -o build/RELEASE/oled.o src/oled.c
avr-gcc -mmcu=atmega328p -DF_CPU="16000000UL" -MD -MP -Wall -Werror -std=c99 -ffunction-sections -fdata-sections -funsigned-char -funsigned-bitfields -fpack-struct -fshort-enums -frename-registers -g -Wa,-ahlmsd=build/RELEASE/display.lst -O2 -DNDEBUG   -c -o build/RELEASE/display.o src/display.c
avr-gcc -mmcu=atmega328p -DF_CPU="16000000UL" -MD -MP -Wall -Werror -std=c99 -ffunction-sections -fdata-sections -funsigned-char -funsigned-bitfields -fpack-struct -fshort-enums -frename-registers -g -Wa,-ahlmsd=build/RELEASE/progmem_image_sprite.lst -O2 -DNDEBUG   -c -o build/RELEASE/progmem_image_sprite.o src/progmem_image_sprite.c
avr-gcc -mmcu=atmega328p -DF_CPU="16000000UL" -MD -MP -Wall -Werror -std=c99 -ffunction-sections -fdata-sections -funsigned-char -funsigned-bitfields -fpack-struct -fshort-enums -frename-registers -g -Wa,-ahlmsd=build/RELEASE/needle_coordinates.lst -O2 -DNDEBUG   -c -o build/RELEASE/needle_coordinates.o src/needle_coordinates.c
avr-gcc -mmcu=atmega328p -DF_CPU="16000000UL" -MD -MP -Wall -Werror -std=c99 -ffunction-sections -fdata-sections -funsigned-char -funsigned-bitfields -fpack-struct -fshort-enums -frename-registers -g -Wa,-ahlmsd=build/RELEASE/needle_sprite.lst -O2 -DNDEBUG   -c -o build/RELEASE/needle_sprite.o src/needle_sprite.c
avr-gcc -mmcu=atmega328p -DF_CPU="16000000UL" -MD -MP -Wall -Werror -std=c99 -ffunction-sections -fdata-sections -funsigned-char -funsigned-bitfields -fpack-struct -fshort-enums -frename-registers -g -Wa,-ahlmsd=build/RELEASE/adc.lst -O2 -DNDEBUG   -c -o build/RELEASE/adc.o src/adc.c
avr-gcc -mmcu=atmega328p -DF_CPU="16000000UL" -MD -MP -Wall -Werror -std=c99 -ffunction-sections -fdata-sections -funsigned-char -funsigned-bitfields -fpack-struct -fshort-enums -frename-registers -g -Wa,-ahlmsd=build/RELEASE/calibration.lst -O2 -DNDEBUG   -c -o build/RELEASE/calibration.o src/calibration.c
avr-gcc -mmcu=atmega328p -DF_CPU="16000000UL" -MD -MP -Wall -Werror -std=c99 -ffunction-sections -fdata-sections -funsigned-char -funsigned-bitfields -fpack-struct -fshort-enums -frename-registers -g -Wa,-ahlmsd=build/RELEASE/main.lst -O2 -DNDEBUG   -c -o build/RELEASE/main.o src/main.c
avr-gcc -mmcu=atmega328p -DF_CPU="16000000UL" -MD -MP -Wall -Werror -std=c99 -ffunction-sections -fdata-sections -funsigned-char -funsigned-bitfields -fpack-struct -fshort-enums -frename-registers -g -Wa,-ahlmsd=build/RELEASE/main -O2 -DNDEBUG  -mmcu=atmega328p -static -Wl,-Map=build/RELEASE/map.map,--cref -Wl,--section-start=.eefixed=0x810080 -Wl,-gc-sections  build/RELEASE/utils.o build/RELEASE/fault.o build/RELEASE/benchmark.o build/RELEASE/ring_buffer.o build/RELEASE/i2c_hw.o build/RELEASE/i2c.o build/RELEASE/oled.o build/RELEASE/display.o build/RELEASE/progmem_image_sprite.o build/RELEASE/needle_coordinates.o build/RELEASE/needle_sprite.o build/RELEASE/adc.o build/RELEASE/calibration.o build/RELEASE/main.o   -o build/RELEASE/main
build/RELEASE/main.o: In function `main':
C:\Users\Wii\Desktop\avr-gcc-214.1.0-x64-windows\bin/src/main.c:160: undefined reference to `IMG_BACKGROUND'
C:\Users\Wii\Desktop\avr-gcc-214.1.0-x64-windows\bin/src/main.c:160: undefined reference to `IMG_BACKGROUND'
C:\Users\Wii\Desktop\avr-gcc-214.1.0-x64-windows\bin/src/main.c:160: undefined reference to `IMG_PEAK_INDICATOR'
C:\Users\Wii\Desktop\avr-gcc-214.1.0-x64-windows\bin/src/main.c:160: undefined reference to `IMG_PEAK_INDICATOR'
C:\Users\Wii\Desktop\avr-gcc-214.1.0-x64-windows\bin/src/main.c:160: undefined reference to `IMG_WATERMARK'
C:\Users\Wii\Desktop\avr-gcc-214.1.0-x64-windows\bin/src/main.c:160: undefined reference to `IMG_WATERMARK'
make: *** [build/RELEASE/main] Error 1

Can you help me please?
thank you🙏

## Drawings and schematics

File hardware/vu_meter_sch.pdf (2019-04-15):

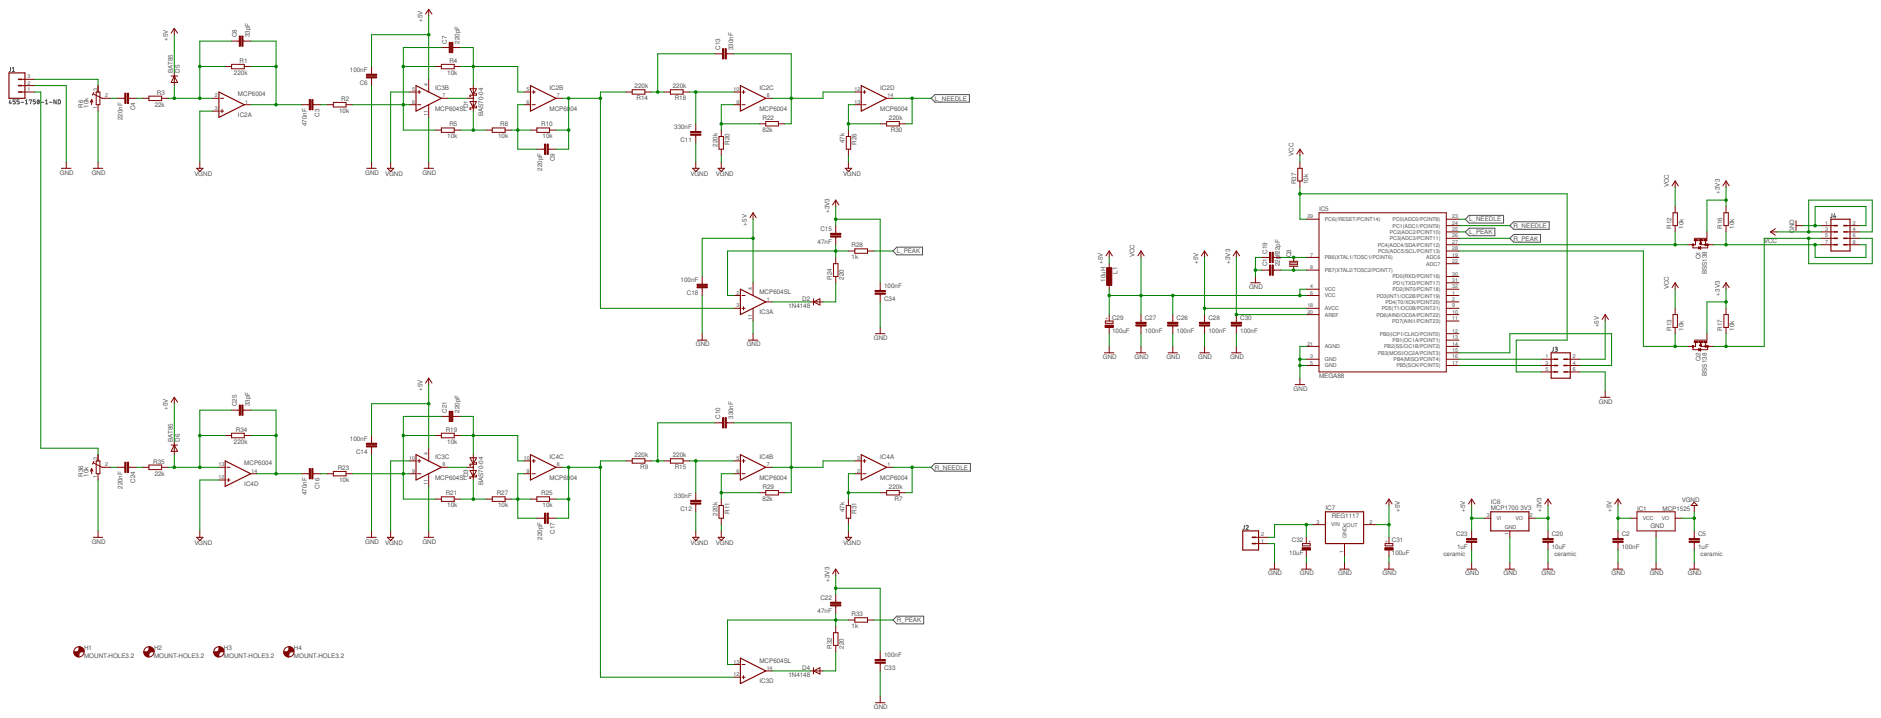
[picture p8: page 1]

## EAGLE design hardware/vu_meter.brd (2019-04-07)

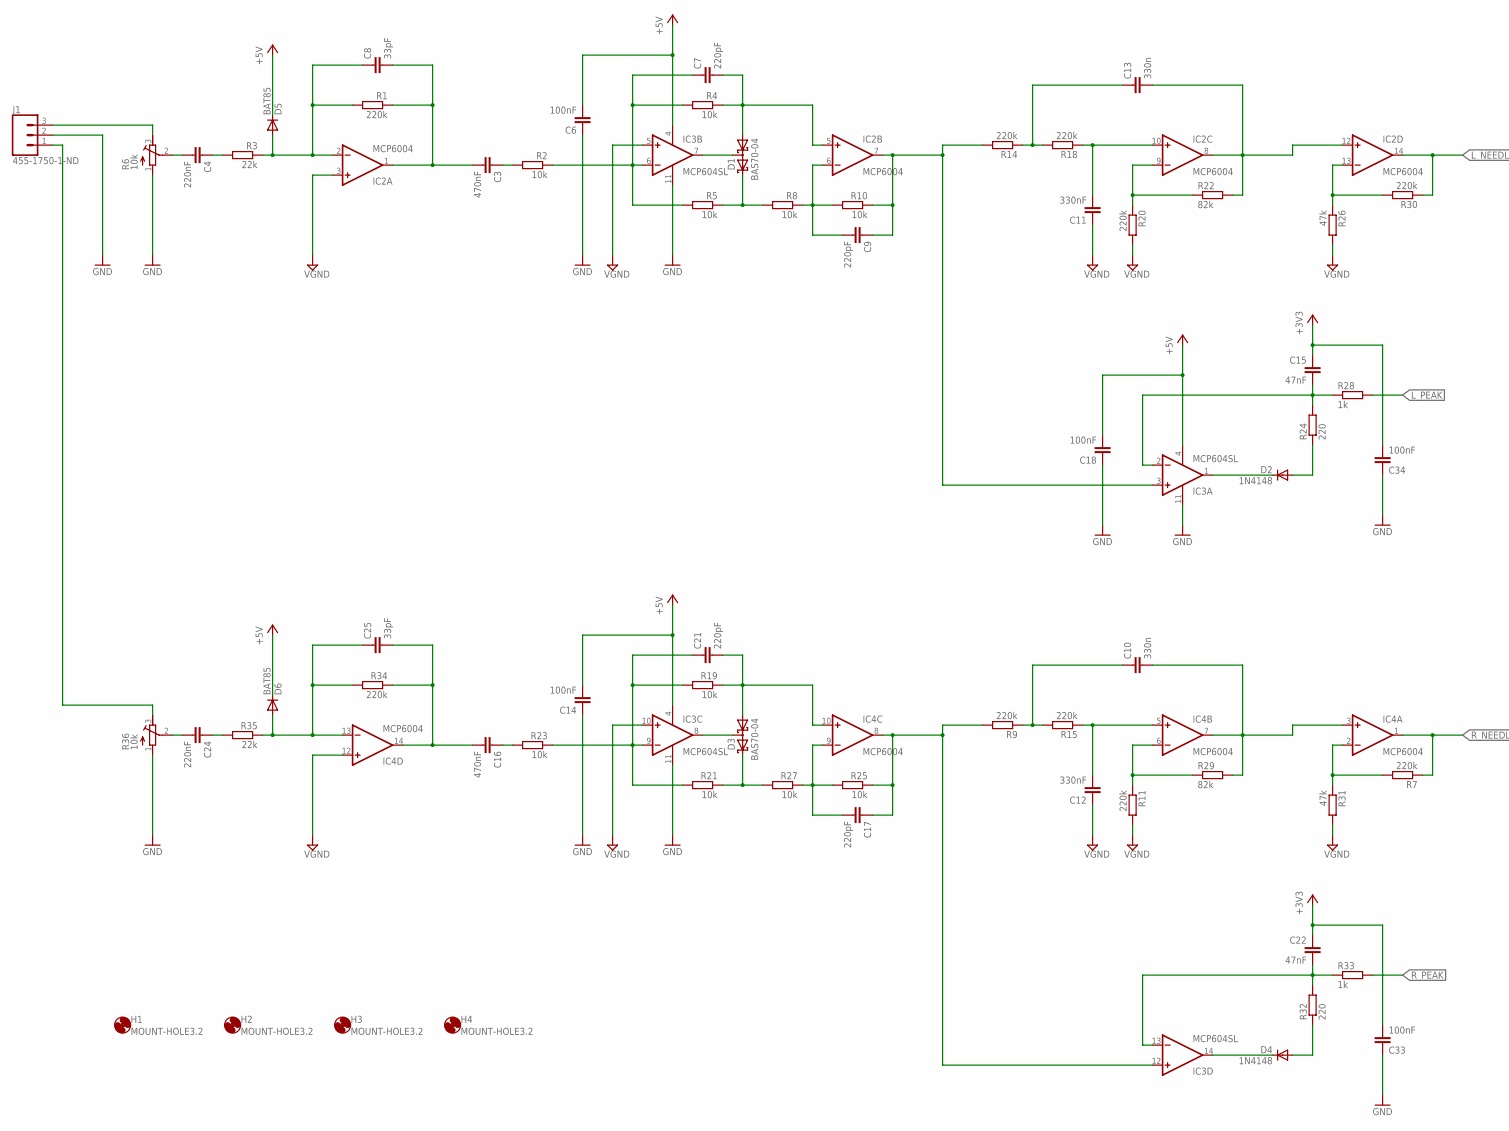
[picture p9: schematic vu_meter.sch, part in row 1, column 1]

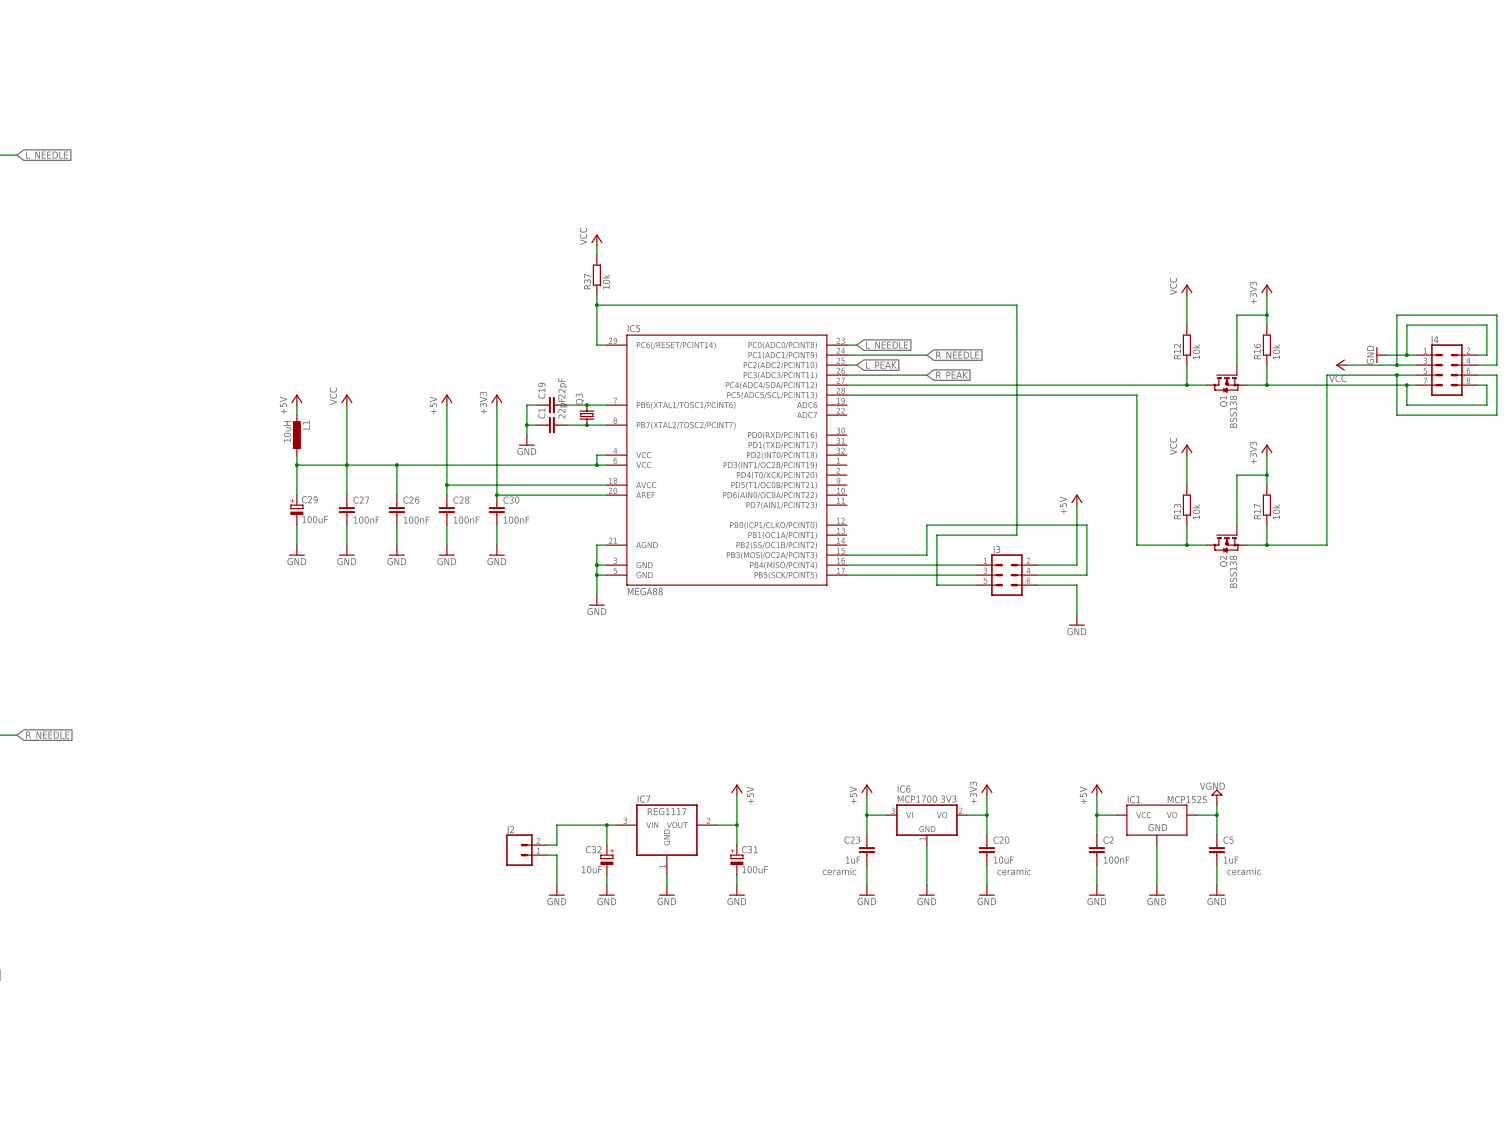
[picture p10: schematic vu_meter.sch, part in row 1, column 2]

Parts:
C1, C19: 22pF; C0805
C2, C6, C14, C18, C26, C27, C28, C30, C33, C34: 100nF; C0805
C3, C16: 470nF; C0805
C4, C24: 220nF; C0805
C5, C23: 1uF; C0805
C7, C9, C17, C21: 220pF; C0805
C8, C25: 33pF; C0805
C10, C13: 330n; C0805
C11, C12: 330nF; C0805
C15, C22: 47nF; C0805
C20: 10uF; C0805
C29, C31: 100uF; B/3528-21R
C32: 10uF; B/3528-21R
D1, D3: BAS70-04; SOT23
D2, D4: 1N4148; MINIMELF
D5, D6: BAT85; MINIMELF
H1, H2, H3, H4: MOUNT-HOLE3.2; 3,2
IC1: MCP1525; SOT23-3
IC2, IC4: MCP6004; SO14
IC3: MCP604SL; SO14
IC5: MEGA88; TQFP32-08
IC6: MCP1700 3V3; SOT23
IC7: REG1117; SOT223
J1: 455-1750-1-ND; 1X03
J2: CONN_02; 1X02
J3: CONN_03X22X3_SILK_MALE_PTH; 2X3
J4: CONN_04X2; 2X4
L1: 10uH; L3216C
Q1, Q2: BSS138; SOT23
Q3: CRYSTALHC49S; HC49/S
R1, R11, R15, R18, R20, R34: 220k; R0805
R2, R4, R5, R8, R10, R12, R13, R16, R17, R19, R21, R23, R25, R27, R37: 10k; R0805
R3, R35: 22k; R0805
R6, R36: 10k; RTRIM3296W
R7, R9, R14, R30: 220k; M0805
R22, R29: 82k; R0805
R24, R32: 220; R0805
R26, R31: 47k; M0805
R28, R33: 1k; R0805

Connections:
+3V3: C15.1, C20.1, C22.1, C30.1, C33.2, C34.2, IC5.20 (AREF), IC6.2 (VO), Q1.1 (G), Q2.1 (G), R16.2, R17.2
+5V: C2.1, C6.2, C14.2, C18.2, C23.1, C28.1, C31.+, D5.C, D6.C, IC1.1 (VCC), IC2.4 (V+), IC3.4 (V+), IC4.4 (V+), IC5.18 (AVCC), IC6.3 (VI), IC7.2 (VOUT), J3.2, L1.2
GND: C1.1, C2.2, C5.2, C6.1, C14.1, C18.1, C19.1, C20.2, C23.2, C26.2, C27.2, C28.2, C29.-, C30.2, C31.-, C32.-, C33.1, C34.1, IC1.3 (GND), IC2.11 (V-), IC3.11 (V-), IC4.11 (V-), IC5.3 (GND), IC5.5 (GND), IC5.21 (AGND), IC6.1 (GND), IC7.1 (GND), J1.2, J2.1, J3.6, J4.1, J4.2, R6.1 (A), R36.1 (A)
GND1: C5.1, C11.1, C12.1, IC1.2 (VO), IC2.3 (+IN), IC3.5 (+IN), IC3.10 (+IN), IC4.12 (+IN), R11.2, R20.2, R26.2, R31.2
IN: J1.3, R6.3 (E)
IN1: J1.1, R36.3 (E)
L_NEEDLE: IC2.14 (OUT), IC5.23 (PC0(ADC0/PCINT8)), R30.1
L_PEAK: IC5.25 (PC2(ADC2/PCINT10)), R28.2
unnamed: IC2.13 (-IN), R26.1, R30.2
unnamed: IC4.2 (-IN), R7.2, R31.1
unnamed: C8.1, D5.A, IC2.2 (-IN), R1.2, R3.1
unnamed: C4.1, R3.2
unnamed: C12.2, IC4.5 (+IN), R15.1
unnamed: C4.2, R6.2 (S)
unnamed: C13.1, R14.1, R18.2
unnamed: C13.2, IC2.8 (OUT), IC2.12 (+IN), R22.2
unnamed: IC4.6 (-IN), R11.1, R29.1
unnamed: D3.2 (C2), R21.1, R27.2
unnamed: C21.1, IC3.9 (-IN), R19.2, R21.2, R23.1
unnamed: C11.2, IC2.10 (+IN), R18.1
unnamed: IC2.9 (-IN), R20.1, R22.1
unnamed: D1.2 (C2), R5.1, R8.2
unnamed: C21.2, D3.1 (A1), IC4.10 (+IN), R19.1
unnamed: C3.2, C8.2, IC2.1 (OUT), R1.1
unnamed: C7.1, IC3.6 (-IN), R2.1, R4.2, R5.2
unnamed: D2.C, IC3.1 (OUT)
unnamed: D3.3 (C1A2), IC3.8 (OUT)
unnamed: C17.2, IC4.9 (-IN), R25.2, R27.1
unnamed: C16.2, C25.2, IC4.14 (OUT), R34.1
unnamed: C16.1, R23.2
unnamed: C7.2, D1.1 (A1), IC2.5 (+IN), R4.1
unnamed: D1.3 (C1A2), IC3.7 (OUT)
unnamed: C9.2, IC2.6 (-IN), R8.1, R10.2
unnamed: C10.1, R9.1, R15.2
unnamed: C10.2, IC4.3 (+IN), IC4.7 (OUT), R29.2
unnamed: C22.2, IC3.13 (-IN), R32.2, R33.1
unnamed: D4.A, R32.1
unnamed: C17.1, IC3.12 (+IN), IC4.8 (OUT), R9.2, R25.1
unnamed: D4.C, IC3.14 (OUT)
unnamed: C25.1, D6.A, IC4.13 (-IN), R34.2, R35.1
unnamed: C24.1, R35.2
unnamed: C24.2, R36.2 (S)
unnamed: C19.2, IC5.7 (PB6(XTAL1/TOSC1/PCINT6)), Q3.2
unnamed: C1.2, IC5.8 (PB7(XTAL2/TOSC2/PCINT7)), Q3.1
unnamed: IC5.15 (PB3(MOSI/OC2A/PCINT3)), J3.4
unnamed: C3.1, R2.2
unnamed: IC5.17 (PB5(SCK/PCINT5)), J3.3
unnamed: IC5.16 (PB4(MISO/PCINT4)), J3.1
unnamed: IC5.29 (PC6(/RESET/PCINT14)), J3.5, R37.1
unnamed: C15.2, IC3.2 (-IN), R24.2, R28.1
unnamed: D2.A, R24.1
unnamed: C32.+, IC7.3 (VIN), J2.2
unnamed: C9.1, IC2.7 (OUT), IC3.3 (+IN), R10.1, R14.2
R_NEEDLE: IC4.1 (OUT), IC5.24 (PC1(ADC1/PCINT9)), R7.1
R_PEAK: IC5.26 (PC3(ADC3/PCINT11)), R33.2
SCL: J4.5, J4.6, Q2.2 (S), R17.1
SCL1: IC5.28 (PC5(ADC5/SCL/PCINT13)), Q2.3 (D), R13.1
SDA: J4.7, J4.8, Q1.2 (S), R16.1
SDA1: IC5.27 (PC4(ADC4/SDA/PCINT12)), Q1.3 (D), R12.1
VCC: C26.1, C27.1, C29.+, IC5.4 (VCC), IC5.6 (VCC), J4.3, J4.4, L1.1, R12.2, R13.2, R37.2

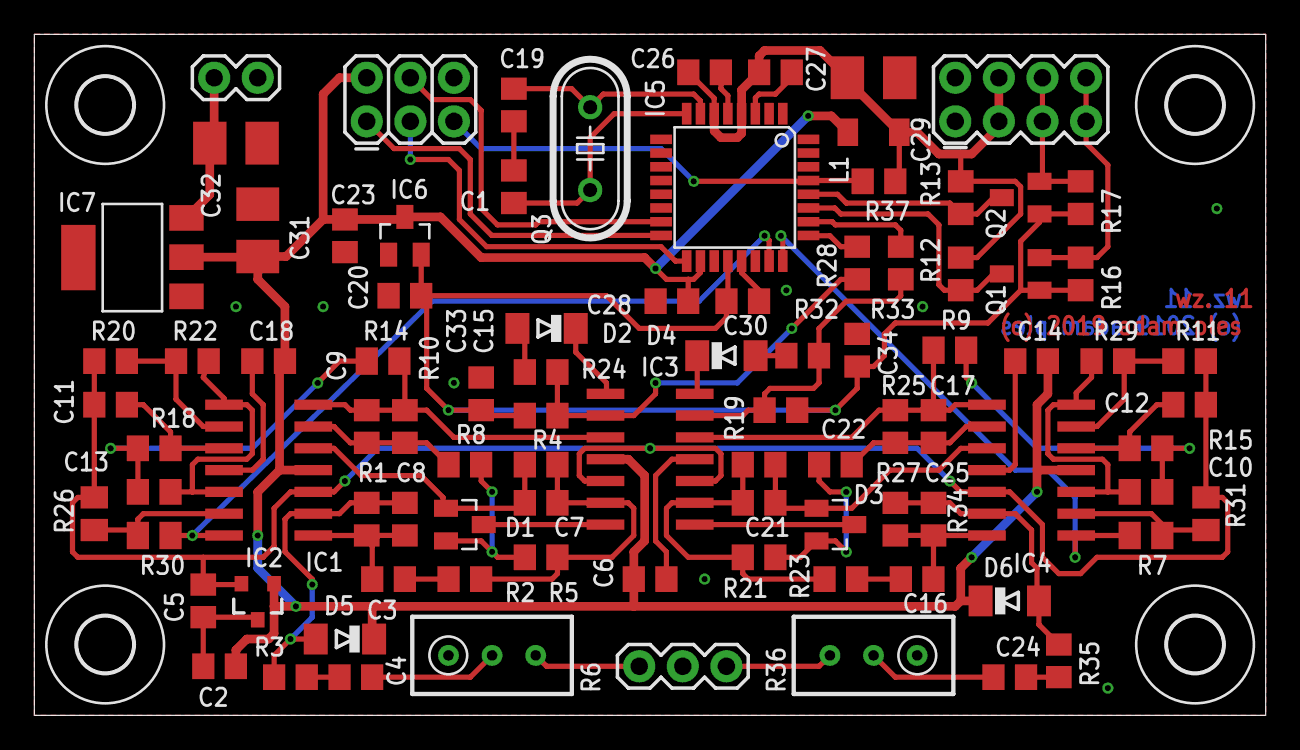
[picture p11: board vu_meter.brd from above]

Board: 2 copper layers, 71.7 x 39.7 mm, 96 parts (0 on the bottom side), 60 nets.

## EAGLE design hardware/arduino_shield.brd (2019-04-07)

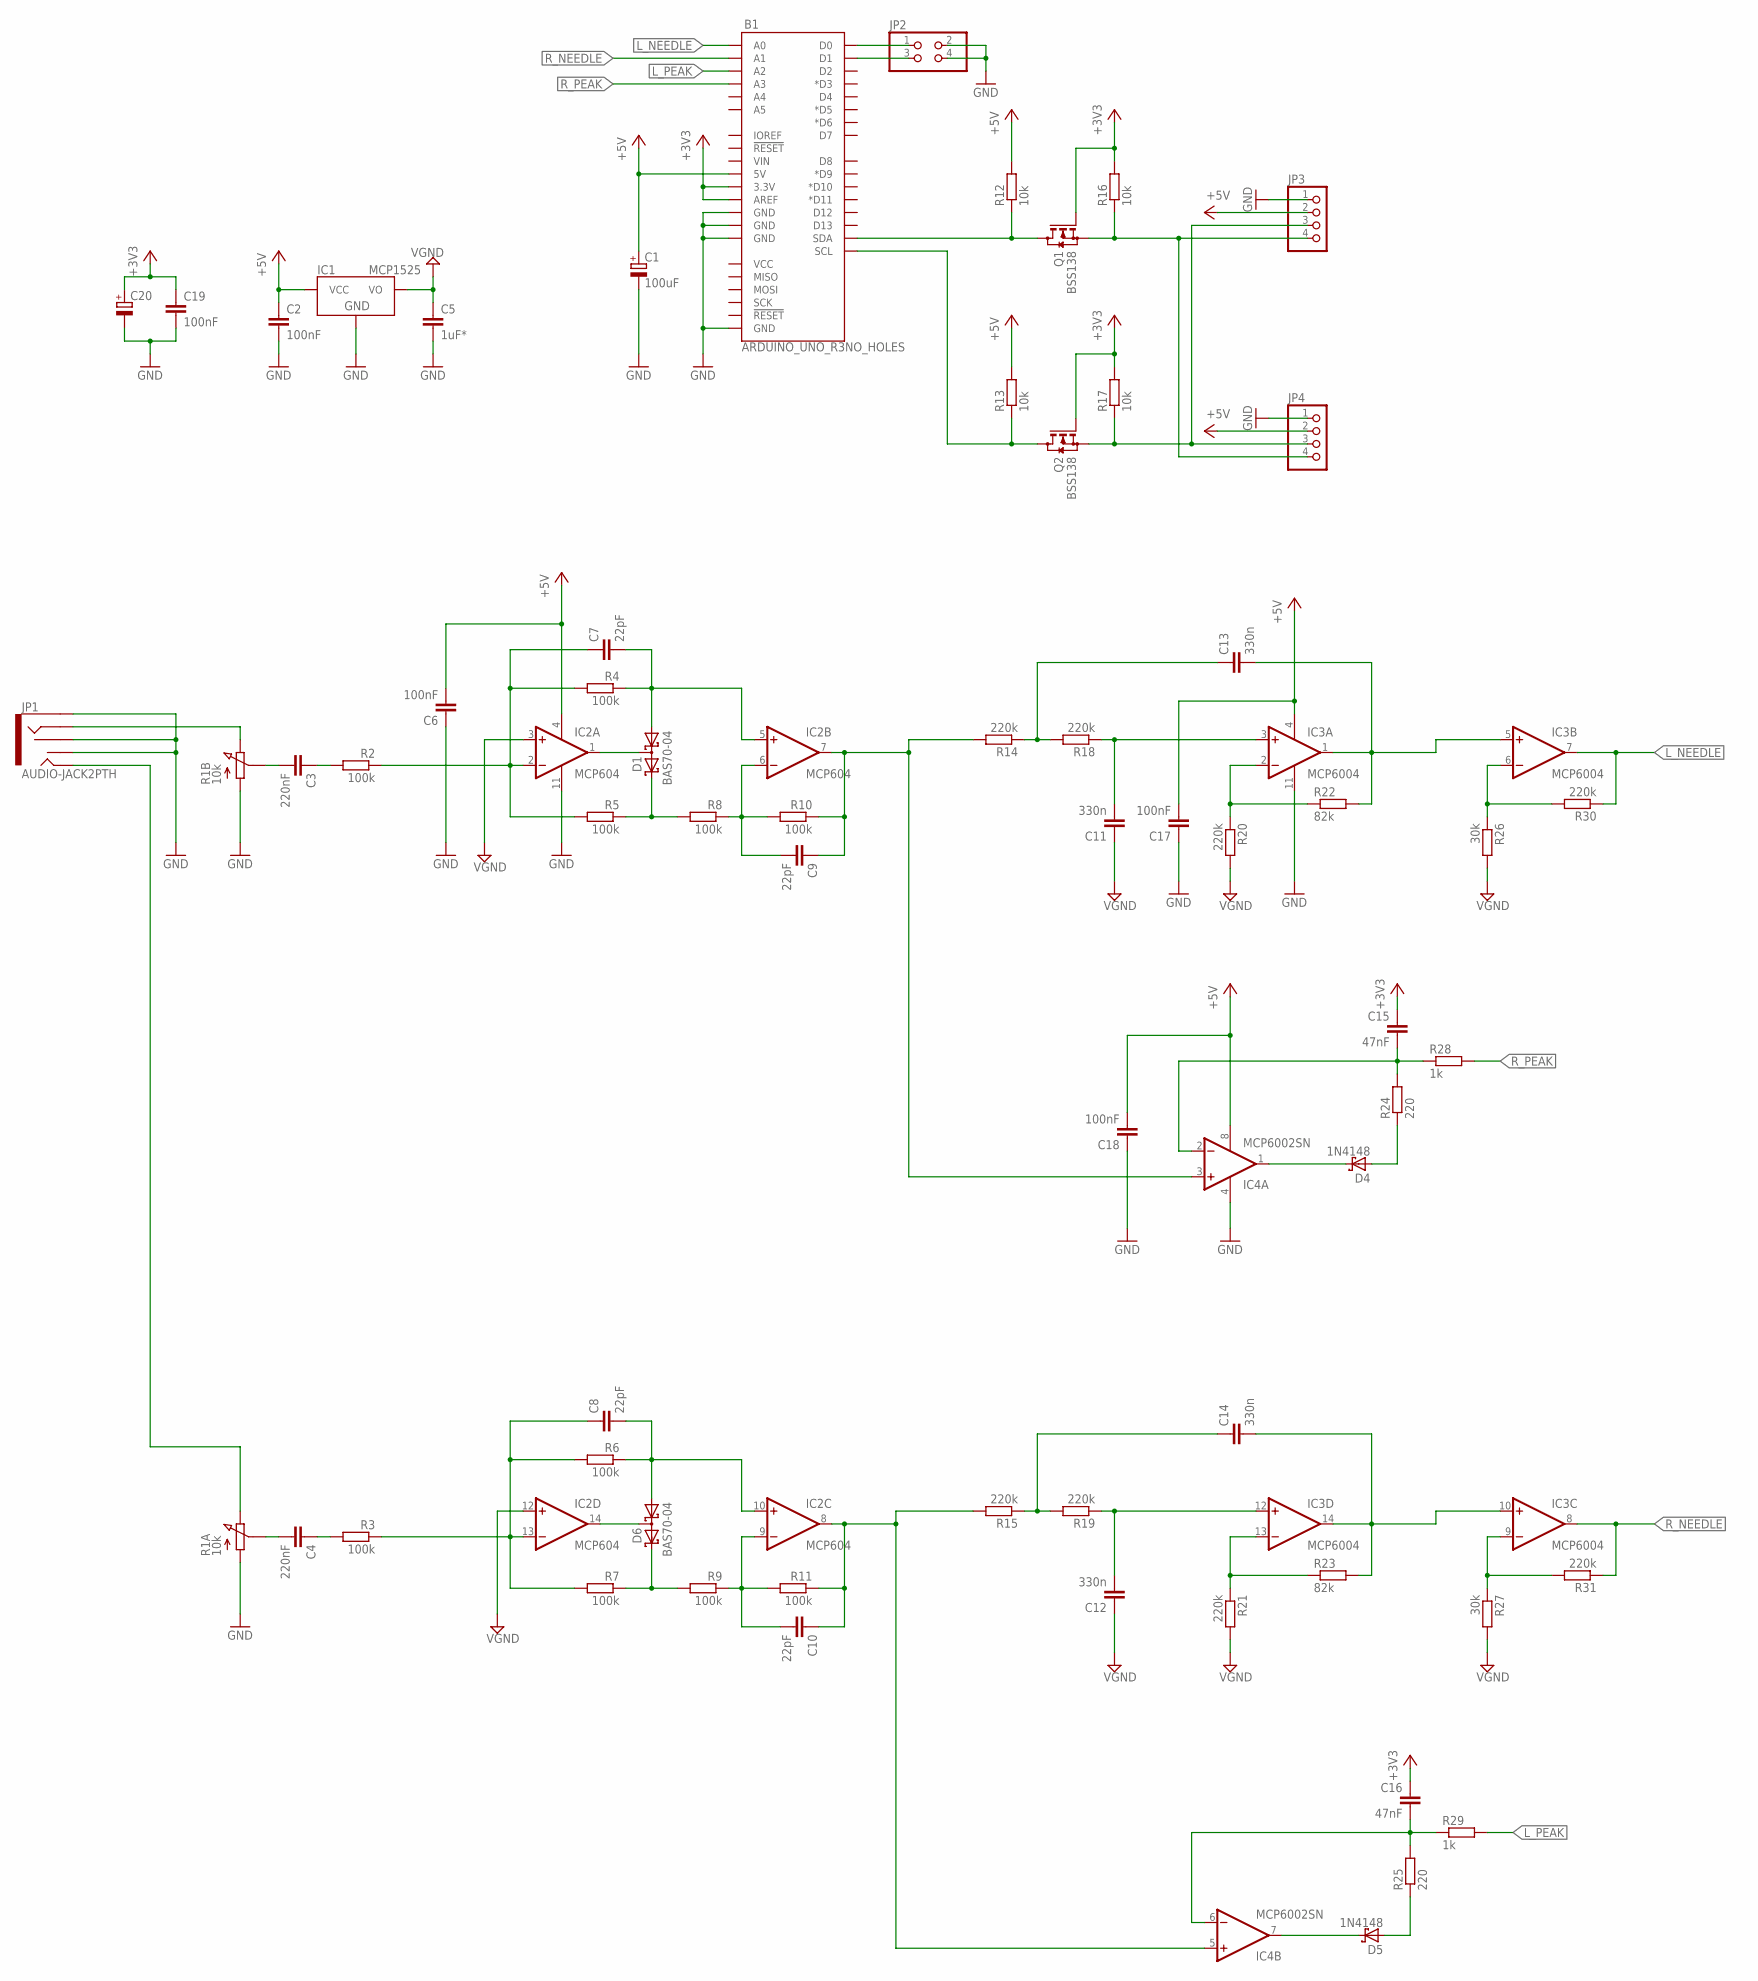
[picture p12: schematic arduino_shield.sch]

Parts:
B1: ARDUINO_UNO_R3NO_HOLES; ARDUINO_R3_NO_HOLES
C1: 100uF; B/3528-21R
C2, C6, C17, C18, C19: 100nF; C0805
C3, C4: 220nF; C0805
C5: 1uF*; C0805
C7, C8, C9, C10: 22pF; C0805
C11, C12, C13, C14: 330n; C0805
C15, C16: 47nF; C0805
C20: CPOL-EUA/3216-18R; A/3216-18R
D1, D6: BAS70-04; SOT23
D4, D5: 1N4148; SOD323_ST
IC1: MCP1525; SOT23-3
IC2: MCP604; SO14
IC3: MCP6004; SO14
IC4: MCP6002SN; SO08
JP1: AUDIO-JACK2PTH; AUDIO-JACK
JP2: PINHD-2X2; 2X02
JP3, JP4: PINHD-1X4; 1X04
Q1, Q2: BSS138; SOT23
R1: 10k; POT1
R2, R3, R4, R5, R6, R7, R8, R9, R10, R11: 100k; R0805
R12, R13, R16, R17: 10k; R0805
R14, R15, R30, R31: 220k; M0805
R18, R19, R20, R21: 220k; R0805
R22, R23: 82k; R0805
R24, R25: 220; R0805
R26, R27: 30k; M0805
R28, R29: 1k; R0805

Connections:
+3V3: B1.3.3V, B1.AREF, C15.1, C16.1, C19.1, C20.+, Q1.1 (G), Q2.1 (G), R16.2, R17.2
+5V: B1.5V, C1.+, C2.1, C6.2, C17.2, C18.2, IC1.1 (VCC), IC2.4 (V+), IC3.4 (V+), IC4.8 (V+), JP3.2, JP4.2, R12.2, R13.2
GND: B1.GND@1 (GND), B1.GND@2 (GND), B1.GND@3 (GND), B1.GND@4 (GND), C1.-, C2.2, C5.2, C6.1, C17.1, C18.1, C19.2, C20.-, IC1.3 (GND), IC2.11 (V-), IC3.11 (V-), IC4.4 (V-), JP1.RSH, JP1.SLEEVE, JP1.TSH, JP2.2, JP2.4, JP3.1, JP4.1, R1.1-1 (A-1), R1.2-1 (A-1)
GND1: C5.1, C11.1, C12.1, IC1.2 (VO), IC2.3 (+IN), IC2.12 (+IN), R20.2, R21.2, R26.2, R27.2
L_NEEDLE: B1.A0, IC3.7 (OUT), R30.1
L_PEAK: B1.A2, R29.2
unnamed: IC3.6 (-IN), R26.1, R30.2
unnamed: B1.D0, JP2.1
unnamed: B1.SDA, Q1.3 (D), R12.1
unnamed: D5.A, R25.1
unnamed: B1.SCL, Q2.3 (D), R13.1
unnamed: B1.D1, JP2.3
unnamed: D5.C, IC4.7 (OUT)
unnamed: C13.1, R14.1, R18.2
unnamed: C13.2, IC3.1 (OUT), IC3.5 (+IN), R22.2
unnamed: C16.2, IC4.6 (-IN), R25.2, R29.1
unnamed: IC3.9 (-IN), R27.1, R31.2
unnamed: C11.2, IC3.3 (+IN), R18.1
unnamed: IC3.2 (-IN), R20.1, R22.1
unnamed: D1.2 (C2), R5.1, R8.2
unnamed: C12.2, IC3.12 (+IN), R19.1
unnamed: C3.2, R1.2-2 (S-2)
unnamed: C7.1, IC2.2 (-IN), R2.1, R4.2, R5.2
unnamed: D4.C, IC4.1 (OUT)
unnamed: IC3.13 (-IN), R21.1, R23.1
unnamed: C14.1, R15.1, R19.2
unnamed: C7.2, D1.1 (A1), IC2.5 (+IN), R4.1
unnamed: D1.3 (C1A2), IC2.1 (OUT)
unnamed: C9.2, IC2.6 (-IN), R8.1, R10.2
unnamed: C14.2, IC3.10 (+IN), IC3.14 (OUT), R23.2
unnamed: D6.2 (C2), R7.1, R9.2
unnamed: C8.1, IC2.13 (-IN), R3.1, R6.2, R7.2
unnamed: C8.2, D6.1 (A1), IC2.10 (+IN), R6.1
unnamed: D6.3 (C1A2), IC2.14 (OUT)
unnamed: C10.2, IC2.9 (-IN), R9.1, R11.2
unnamed: C10.1, IC2.8 (OUT), IC4.5 (+IN), R11.1, R15.2
unnamed: C4.2, R1.1-2 (S-2)
unnamed: C4.1, R3.2
unnamed: C3.1, R2.2
unnamed: JP1.RING, R1.2-3 (E-3)
unnamed: JP1.TIP, R1.1-3 (E-3)
unnamed: C15.2, IC4.2 (-IN), R24.2, R28.1
unnamed: D4.A, R24.1
unnamed: C9.1, IC2.7 (OUT), IC4.3 (+IN), R10.1, R14.2
R_NEEDLE: B1.A1, IC3.8 (OUT), R31.1
R_PEAK: B1.A3, R28.2
SCL: JP3.3, JP4.3, Q2.2 (S), R17.1
SDA: JP3.4, JP4.4, Q1.2 (S), R16.1

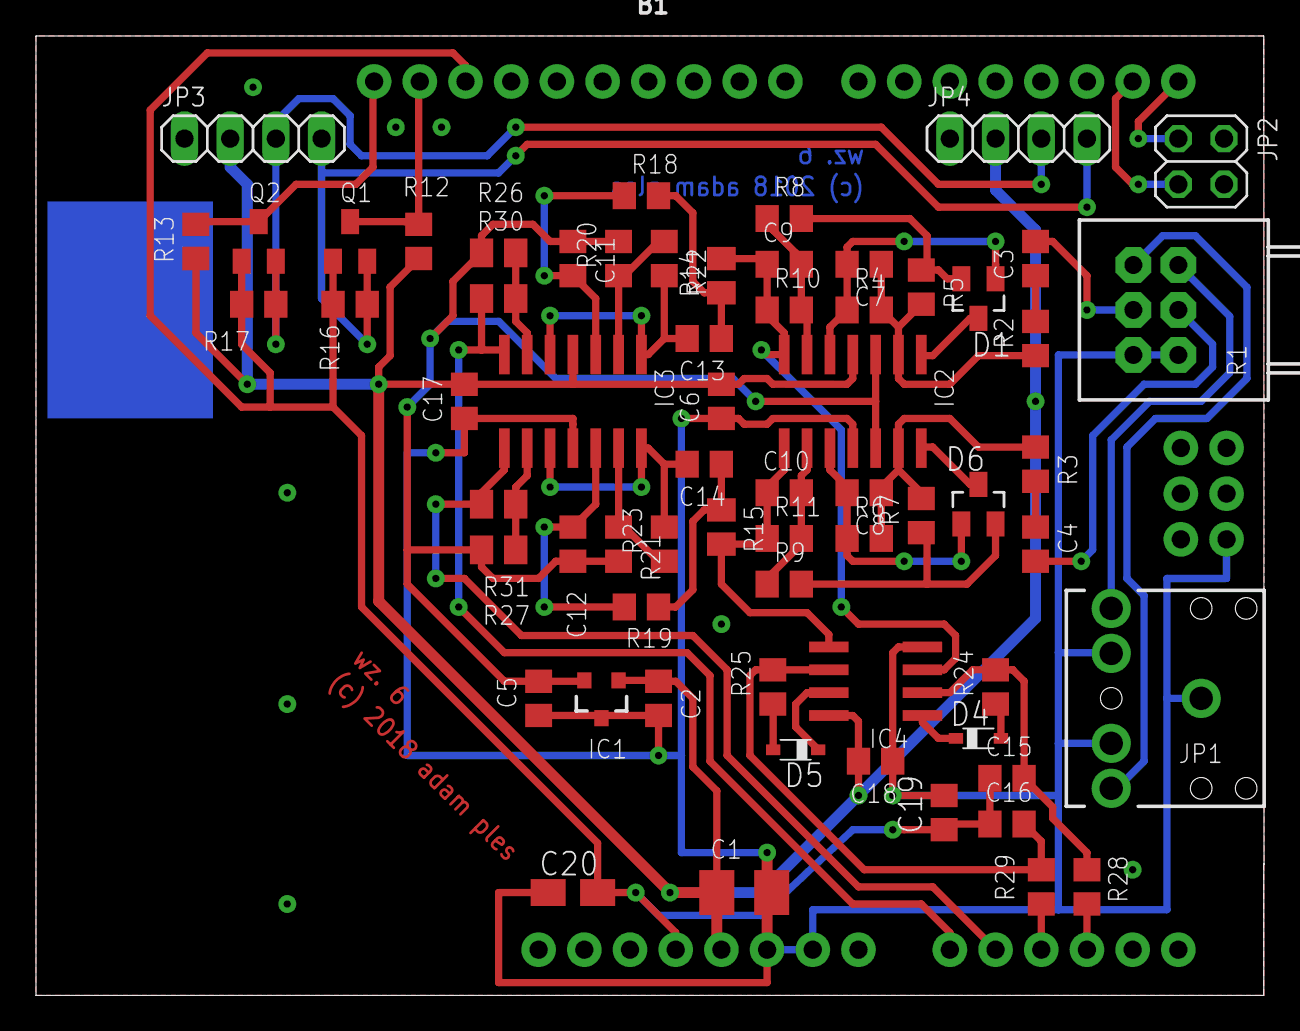
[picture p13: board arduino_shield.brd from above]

Board: 2 copper layers, 68.3 x 53.3 mm, 66 parts (0 on the bottom side), 48 nets.

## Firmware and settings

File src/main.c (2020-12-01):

#include <stdlib.h>
#include <stdlib.h>
#include <math.h>
#include <avr/interrupt.h>
#include <avr/pgmspace.h>
#include <avr/eeprom.h>
#include "config.h"
#include "utils.h"
#include "assert.h"
#include "i2c.h"
#include "images.h"
#include "oled.h"
#include "display.h"
#include "progmem_image_sprite.h"
#include "needle_sprite.h"
#include "benchmark.h"
#include "adc.h"
#include "calibration.h"


calibration_data_t CALIBRATION_LEFT EEFIXED = CALIBRATION_INITIALIZER;
calibration_data_t CALIBRATION_RIGHT EEFIXED = CALIBRATION_INITIALIZER;


typedef struct vu_meter_t_ {
  display_t display;
  calibration_t calibration;
  bool flipped;
  progmem_image_sprite_t background;
  needle_sprite_t needle;
  progmem_image_sprite_t peak_indicator;
#if ENABLE_WATERMARK
  progmem_image_sprite_t watermark;
#endif
  uint8_t peak_timer;
} vu_meter_t;


void
vu_meter_init(vu_meter_t *meter,
              int8_t address,
              calibration_data_t *calibration_eeprom,
              bool flipped,
              const uint8_t *background_image,
              const uint8_t *peak_indicator_image
#if ENABLE_WATERMARK
              , const uint8_t *watermark_image
#endif
              )
{
  meter->flipped = flipped;

  calibration_init(&(meter->calibration), calibration_eeprom);

  display_init(&(meter->display), address);
  progmem_image_sprite_init(&(meter->background), background_image, 0, 0);

  display_add_sprite(&(meter->display), &(meter->background.sprite));

#if ENABLE_WATERMARK
  progmem_image_sprite_init(
    &(meter->watermark),
    watermark_image,
    WATERMARK_POSITION_X,
    WATERMARK_POSITION_Y
  );

  display_add_sprite(&(meter->display), &(meter->watermark.sprite));
#endif

  progmem_image_sprite_init(
    &(meter->peak_indicator),
    peak_indicator_image,
    PEAK_POSITION_X,
    PEAK_POSITION_Y
  );
  display_add_sprite(&(meter->display), &(meter->peak_indicator.sprite));

  needle_sprite_init(&(meter->needle));
  needle_sprite_draw(&(meter->needle), 0);
  display_add_sprite(&(meter->display), &(meter->needle.sprite));

  meter->peak_indicator.sprite.visible = false;
}


void
vu_meter_update(vu_meter_t *meter, uint16_t needle_level, uint16_t peak_level)
{
  #if INCLUDE_CALIBRATION
    calibration_run(
      &(meter->calibration),
      needle_level,
      peak_level
    );
  #endif

  uint8_t angle = calibration_adc_to_angle(&(meter->calibration), needle_level);
  bool peak;

#if PEAK_IS_ZERO_VU
  peak = (angle > NEEDLE_ZERO_VU_ANGLE);
#else
  peak = calibration_adc_to_peak(&(meter->calibration), peak_level);
#endif

  if (meter->flipped) {
    angle = 255 - angle;
  }

  if (peak) {
    meter->peak_timer = 10;
  }
  else if (meter->peak_timer > 0) {
    --(meter->peak_timer);
  }

  bool new_visible = (meter->peak_timer > 0);
  meter->peak_indicator.sprite.changed = (meter->peak_indicator.sprite.visible != new_visible);
  meter->peak_indicator.sprite.visible = new_visible;

  needle_sprite_draw(&(meter->needle), angle);
  display_update(&(meter->display));
}


void vu_meter_splash(vu_meter_t *meter, const uint8_t *image)
{
  const uint8_t *background_tmp = meter->background.data;
  uint8_t sprites_n = meter->display.sprites_n;

  progmem_image_sprite_init(&(meter->background), image, 0, 0);
  meter->display.sprites_n = 1;

  display_force_full_update(&(meter->display));
  display_update(&(meter->display));

  progmem_image_sprite_init(&(meter->background), background_tmp, 0, 0);
  meter->display.sprites_n = sprites_n;
}


vu_meter_t VU_METER_L;
vu_meter_t VU_METER_R;


int main(void)
{
  watchdog_init();
  i2c_init();
  adc_init();
  calibration_hw_init();
#if OLED_INCLUDE_RESET
  oled_reset();
#endif
  sei();

  watchdog_reset();

  vu_meter_init(
    &VU_METER_L,
    DISPLAY_LEFT_ADDRESS,
    &CALIBRATION_LEFT,
    DISPLAY_LEFT_FLIPPED,
    DISPLAY_LEFT_BACKGROUND,
    DISPLAY_LEFT_PEAK_INDICATOR
#if ENABLE_WATERMARK
    , DISPLAY_LEFT_WATERMARK
#endif
  );

  vu_meter_init(
    &VU_METER_R,
    DISPLAY_RIGHT_ADDRESS,
    &CALIBRATION_RIGHT,
    DISPLAY_RIGHT_FLIPPED,
    DISPLAY_RIGHT_BACKGROUND,
    DISPLAY_RIGHT_PEAK_INDICATOR
#if ENABLE_WATERMARK
    , DISPLAY_RIGHT_WATERMARK
#endif
  );

  #if ENABLE_SPLASH_SCREEN
    vu_meter_splash(&VU_METER_L, DISPLAY_LEFT_SPLASH);
    vu_meter_splash(&VU_METER_R, DISPLAY_RIGHT_SPLASH);

    oled_set_display_on(&(VU_METER_L.display.device), true);
    oled_set_display_on(&(VU_METER_R.display.device), true);

    delay_ms(SPLASH_SCREEN_TIME_MS);

    oled_set_display_on(&(VU_METER_L.display.device), false);
    oled_set_display_on(&(VU_METER_R.display.device), false);
  #endif

  bool is_on = false;
  adc_data_t adc_data;

  for (int i = 0; true; ++i) {
    watchdog_reset();

    adc_get(&adc_data);

    if (i % 10 == 0) {
      adc_reset_peak(true, true);
      adc_reset_peak(false, false);
    }

    vu_meter_update(&VU_METER_L, adc_data.l_needle, adc_data.l_peak);
    vu_meter_update(&VU_METER_R, adc_data.r_needle, adc_data.r_peak);

    if (!is_on && i > BLANK_TIME_FRAMES) {
      oled_set_display_on(&(VU_METER_L.display.device), true);
      oled_set_display_on(&(VU_METER_R.display.device), true);
      is_on = true;
    }
  }

  while (1);
}

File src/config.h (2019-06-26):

#ifndef CONFIG_H
#define CONFIG_H

/* Constants -- do not modify */

#define I2C_DRIVER_ASYNC (0)
#define I2C_DRIVER_SYNC (1)

#define OLED_DRIVER_SH1106 (1)
#define OLED_DRIVER_SSD1305 (2)
#define OLED_DRIVER_SSD1306 (3)
#define OLED_DRIVER_SSD1309 (4)

/* End of constants */


#define I2C_DRIVER (I2C_DRIVER_SYNC)
#define I2C_CLOCK (400000L)

#define OLED_DRIVER (OLED_DRIVER_SH1106)
#define OLED_BRIGHTNESS (0xff)
#define OLED_DRAW_BUFFER_SIZE (8)
#define OLED_INCLUDE_RESET (0)

#define OLED_RESET_DDR (DDRB)
#define OLED_RESET_PORT (PORTB)
#define OLED_RESET_P (PB3)

#define DISPLAY_A_ADDRESS (0x7A)
#define DISPLAY_B_ADDRESS (0x78)


#define INCLUDE_CALIBRATION (1)

#define CALIBRATION_ZERO_PORT (PORTB)
#define CALIBRATION_ZERO_PIN (PINB)
#define CALIBRATION_ZERO_P (PB4)

#define CALIBRATION_REF_PORT (PORTB)
#define CALIBRATION_REF_PIN (PINB)
#define CALIBRATION_REF_P (PB5)

#define CALIBRATION_RESET_PORT (PORTB)
#define CALIBRATION_RESET_PIN (PINB)
#define CALIBRATION_RESET_P (PB3)


#define ADC_CHANNEL_L_NEEDLE (0)
#define ADC_CHANNEL_L_PEAK (2)
#define ADC_CHANNEL_R_NEEDLE (1)
#define ADC_CHANNEL_R_PEAK (3)


#define NEEDLE_MIN_ANGLE (0)
#define NEEDLE_MAX_ANGLE (255)
#define NEEDLE_ZERO_VU_ANGLE (181)
#define PEAK_LEVEL 63 / 10


#define ENABLE_WATERMARK (1)
#define ENABLE_SPLASH_SCREEN (0)
#define SPLASH_SCREEN_TIME_MS (3000)
#define BLANK_TIME_FRAMES (10)

#define PEAK_POSITION_X (107)
#define PEAK_POSITION_Y (7)
#define WATERMARK_POSITION_X (0)
#define WATERMARK_POSITION_Y (7)

#define DISPLAY_LEFT_ADDRESS (DISPLAY_A_ADDRESS)
#define DISPLAY_LEFT_FLIPPED (0)
#define DISPLAY_LEFT_BACKGROUND IMG_BACKGROUND
#define DISPLAY_LEFT_PEAK_INDICATOR IMG_PEAK_INDICATOR
#define DISPLAY_LEFT_SPLASH IMG_NONE
#define DISPLAY_LEFT_WATERMARK IMG_WATERMARK

#define DISPLAY_RIGHT_ADDRESS (DISPLAY_B_ADDRESS)
#define DISPLAY_RIGHT_FLIPPED (0)
#define DISPLAY_RIGHT_BACKGROUND IMG_BACKGROUND
#define DISPLAY_RIGHT_PEAK_INDICATOR IMG_PEAK_INDICATOR
#define DISPLAY_RIGHT_SPLASH IMG_NONE
#define DISPLAY_RIGHT_WATERMARK IMG_WATERMARK

#endif /* CONFIG_H */

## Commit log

2017-11-13 Simple application with VU meter background and flashing peak indicator.
    - asynchronous I2C library with buffering and client queue,
    - initial SSD1306 routines with support for 2 displays connected via I2C,
    - converting images from PNG to C code,
    - drawing images on displays,
    - ~3KB of FLASH used (including images).
2017-11-13 I2C queue changed from single-linked list to ring buffer.
    Added debug LCD display, only for development.
2017-11-23 Introduced composite rendering (very slow)
    benchmark.c: added to profile rendering code
    display.c: composite rendering implementation
    drawing.c: needle sprite rendering
    i2c.c: removed debug LED indicator, added more assertions
    lcd.c: resetting pins after transmission
    ring_buffer.c: refactored assertions for external use, added function
    to check for empty buffer
    ssd1306.c: refactoring, compatibility with i2c driver
    [config.h]
2017-11-23 Created journal file to track progress and ideas
    ... including entry for today.
2017-11-26 Double buffering implemented in I2C driver
2017-11-30 I2C rewrite work in progress
2017-11-30 I2C driver rewritten and operational
2017-11-30 Added caching of next command to I2C driver
2017-11-30 Code cleanup
    - I2C hw functions moved to it's own header
    - image sprite moved to separate object file
    - removed accidentaly added lst file
    - min/max functions moved to header
2017-11-30 Better resolution benchmark + minor bug fixes
    [main.c]
2017-12-01 Rework and cleanup of display and SSD1306 driver
    [main.c]
2017-12-14 OLED display initialization moved to driver
2017-12-14 Needles are now controlled by separate ADC channels
2017-12-19 Added synchronous I2C driver
    Slower, but much smaller in terms of code size and memory usage.
2018-01-10 Fixed swapped MOSFET pins on OLED connection diagram
2018-01-19 Added analog simulation (rectifier + ballistics) schematic
2018-01-19 Short description of analog circuitry added to README.md
2018-03-18 Fixed configuration changed by mistake
    [config.h]
2018-05-14 Fixed update of peak indicator
    [main.c]
2018-05-21 Added preliminary Eagle files (schematic + PCB)
    [vu_meter.brd, vu_meter.sch]
2018-05-21 Revert "Added preliminary Eagle files (schematic + PCB)"
    This reverts commit eb782ed89749604550bede436b3c459ceac1df2c.
    [vu_meter.brd, vu_meter.sch]
2018-06-04 Preparation to add different OLED driver
2018-08-04 Updated schematic and added bill of materials
    [bom.ods, vu_meter.brd, vu_meter.sch]
2018-09-30 Updates to design & build process
    [bom.ods, vu_meter.brd, vu_meter.sch]
2019-03-12 Changed I2C driver for lower flash footprint
2019-03-19 Updated SSD1306 driver + additional artwork
2019-03-25 SSD1305 and SSD1309 drivers
2019-03-25 Fixed "reset to factory defaults" hw config
    [config.h]
2019-03-25 Fixed display enabling delay
    [oled_ssd1306.c]
2019-04-07 Added hardware documentation
    [bom.ods, vu_meter.brd, vu_meter_2.brd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]
2019-04-07 Added PCB image
2019-04-07 Added gerber files and Arduino shield documentation
    [arduino_shield.brd, arduino_shield.sch]
2019-04-15 Fixed sch and brd names and added pdf schematic
    [vu_meter.brd, vu_meter.sch]
2019-06-26 Added missing defines in config.h
    [config.h, oled_sh1106.c, oled_ssd1306.c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]
2019-06-26 Fixed factory reset function
    [main.c]
2019-06-26 Added script for making releases
    [vu_meter_2.brd, vu_meter_2.sch]
2019-06-26 Fixed release script and watermark
    [config.h, main.c]

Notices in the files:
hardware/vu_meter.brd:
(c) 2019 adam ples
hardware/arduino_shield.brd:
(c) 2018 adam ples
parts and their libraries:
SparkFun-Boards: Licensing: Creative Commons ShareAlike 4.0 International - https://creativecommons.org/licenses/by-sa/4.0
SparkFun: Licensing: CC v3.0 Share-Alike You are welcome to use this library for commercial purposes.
